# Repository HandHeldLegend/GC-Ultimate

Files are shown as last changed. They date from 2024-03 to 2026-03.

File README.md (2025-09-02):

# GC-Ultimate
This is the official Github page for the GC Ultimate from Hand Held Legend.

## Software and PCB License
<br />This firmware and PCB model are licensed under a <a rel="license" href="http://creativecommons.org/licenses/by-nc-sa/3.0/">Creative Commons Attribution-NonCommercial-ShareAlike 3.0 Unported License</a>.

## 3D Models License

<br />The 3D shell, buttons, and other associated models are licensed under a <a rel="license" href="http://creativecommons.org/licenses/by/4.0/">Creative Commons Attribution 4.0 International License</a>.

## Attributions

Resources Cross-Referenced for component placement and other spacing detail:
- 3D Scans by Wesk
- GCC CAD Model by GearHawk
- PhobGCC PCB
- 3D models for the ergonomic trigger reference were provided with full permission from *YaBoiMikey*

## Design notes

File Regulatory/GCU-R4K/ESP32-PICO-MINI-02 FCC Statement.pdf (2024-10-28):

9 U.S. FCC Statement

# 9 U.S. FCC Statement

Integration instructions for host product manufacturers according to KDB 996369 D03 OEM Manual v01:

1. List of applicable FCC rules
FCC Part 15 Subpart C 15.247 & 15.209
2. Specific operational use conditions
The module is a module with WiFi and BR,EDR,BLE function.
- Operation Frequency: WiFi 2412 ~2462 MHz;BT: 2402 ~ 2480 MHz
- Number of Channel:WiFi:12 ;BT: 40
- Modulation:WiFi:DSSS/OFDM ;BT:GFSK//4-DQPSK/8DPSK
- Type: PCB Antenna
- Gain: 3.96 dBi Max.

The module can be used for IoT applications with a maximum 3.96 dBi antenna. The host manufacturer installing this module into their product must ensure that the final composit product complies with the FCC requirements by a technical assessment or evaluation to the FCC rules, including the transmitter operation. The host manufacturer has to be aware not to provide information to the end user regarding how to install or remove this RF module in the user’s manual of the end product which integrates this module. The end user manual shall include all required regulatory information/warning as show in this manual.

3. Limited module procedures
Not applicable. The module is a single module and complies with the requirement of FCC Part 15.212.
4. Trace antenna designs
Not applicable. The module has its own antenna, and does not need a host’s printed board microstrip trace antenna, etc.
5. RF exposure considerations
The module must be installed in the host equipment such that at least 20cm is maintained between the antenna and users’ body; and if RF exposure statement or module layout is changed, then the host product manufacturer required to take responsibility of the module through a change in FCC ID or new application. The FCC ID of the module cannot be used on the final product. In these circumstances, the host manufacturer will be responsible for re-evaluating the end product (including the transmitter) and obtaining a separate FCC authorization.
6. Antennas
Antenna Specification are as follows:
- Type: PCB Antenna
- Gain: 3.96 dBi
- Type: Ipex Antenna
- Gain: 2.33 dBi

This device is intended only for host manufacturers under the following conditions:

- The transmitter module may not be co-located with any other transmitter or antenna.
Espressif Systems | 29 Submit Documentation Feedback
ESP32-PICO-MINI-02 & PICO-MINI-02U Datasheet v1.0

- The module shall be only used with the external antenna(s) that has been originally tested and certified with this module.
- The antenna must be either permanently attached or employ a ‘unique’ antenna coupler.

As long as the conditions above are met, further transmitter test will not be required. However, the host manufacturer is still responsible for testing their end-product for any additional compliance requirements required with this module installed (for example, digital device emissions, PC peripheral requirements, etc.).

7. Label and compliance information
Host product manufacturers need to provide a physical or e-label stating “Contains FCC ID: 2AC7Z-ESPPICOMINI” with their finished product.
8. Information on test modes and additional testing requirements
- Operation Frequency:WiFi 2412 ~2462 MHz;BT: 2402 ~ 2480 MHz
- Number of Channel:WiFi:12 ;BT: 40
- Modulation: WiFi:DSSS/OFDM ;BT:GFSK//4-DQPSK/8DPSK

Host manufacturer must perform test of radiated & conducted emission and spurious emission, etc., according to the actual test modes for a stand-alone modular transmitter in a host, as well as for multiple simultaneously transmitting modules or other transmitters in a host product. Only when all the test results of test modes comply with FCC requirements, then the end product can be sold legally.

9. Additional testing, Part 15 Subpart B compliant
The modular transmitter is only FCC authorized for FCC Part 15 Subpart C 15.247 & 15.209 and that the host product manufacturer is responsible for compliance to any other FCC rules that apply to the host not covered by the modular transmitter grant of certification. If the grantee markets their product as being Part 15 Subpart B compliant (when it also contains unintentional-radiator digital circuity), then the grantee shall provide a notice stating that the final host product still requires Part 15 Subpart B compliance testing with the modular transmitter installed.

This equipment has been tested and found to comply with the limits for a Class B digital device, pursuant to Part15 of the FCC Rules. These limits are designed to provide reasonable protection against harmful interference in a residential installation. This equipment generates, uses and can radiate radio frequency energy and, if not installed and used in accordance with the instructions, may cause harmful interference to radio communications. However, there is no guarantee that interference will not occur in a particular installation. If this equipment does cause harmful interference to radio or television reception, which can be determined by turning the equipment off and on, the user is encouraged to try to correct the interference by one of the following measures:

- Reorient or relocate the receiving antenna.
- Increase the separation between the equipment and receiver.
- Connect the equipment into an outlet on a circuit different from that to which the receiver is connected.
- Consult the dealer or an experienced radio/TV technician for help.

This device complies with Part 15 of the FCC Rules. Operation is subject to the following two conditions:

- This device may not cause harmful interference.
- This device must accept any interference received, including interference that may cause undesired operation.

Caution:

Any changes or modifications not expressly approved by the party responsible for compliance could void the user’s

authority to operate the equipment.

This equipment complies with FCC RF radiation exposure limits set forth for an uncontrolled environment. This device and its antenna must not be co-located or operating in conjunction with any other antenna or transmitter. The antennas used for this transmitter must be installed to provide a separation distance of at least 20 cm from all persons and must not be co-located or operating in conjunction with any other antenna or transmitter.

OEM Integration Instructions

This device is intended only for OEM integrators under the following conditions:

- The transmitter module may not be co-located with any other transmitter or antenna.
- The module shall be only used with the external antenna(s) that has been originally tested and certified with this module.

As long as the conditions above are met, further transmitter test will not be required. However, the OEM integrator is still responsible for testing their end-product for any additional compliance requirements required with this module installed (for example, digital device emissions, PC peripheral requirements, etc.).

Validity of Using the Module Certification

In the event that these conditions cannot be met (for example certain laptop configurations or co-location with another transmitter), then the FCC authorization for this module in combination with the host equipment is no longer considered valid and the FCC ID of the module cannot be used on the final product. In these circumstances, the OEM integrator will be responsible for re-evaluating the end product (including the transmitter) and obtaining a separate FCC authorization.

End Product Labeling

The final end product must be labeled in a visible area with the following: “Contains Transmitter Module FCC ID: 2AC7Z-ESPPICOMINI”.

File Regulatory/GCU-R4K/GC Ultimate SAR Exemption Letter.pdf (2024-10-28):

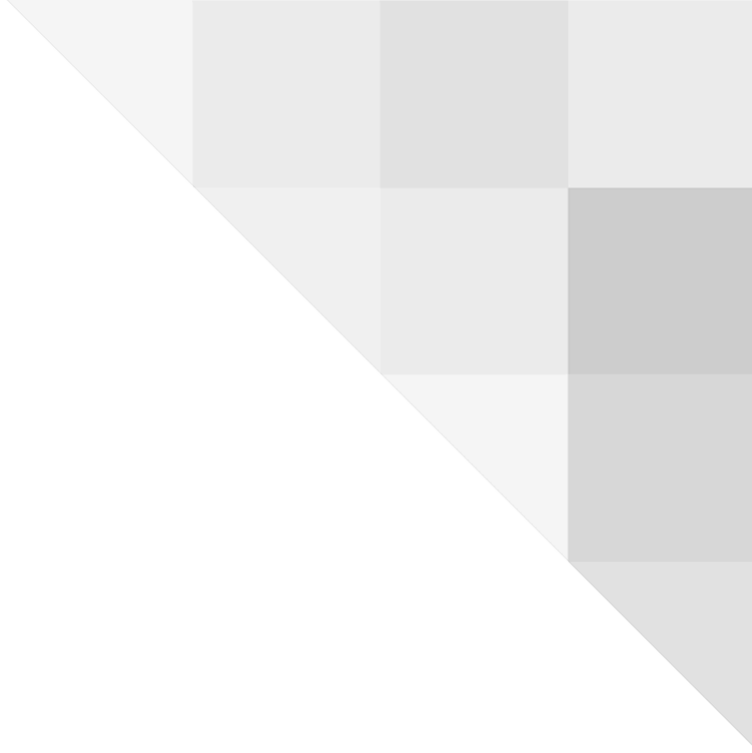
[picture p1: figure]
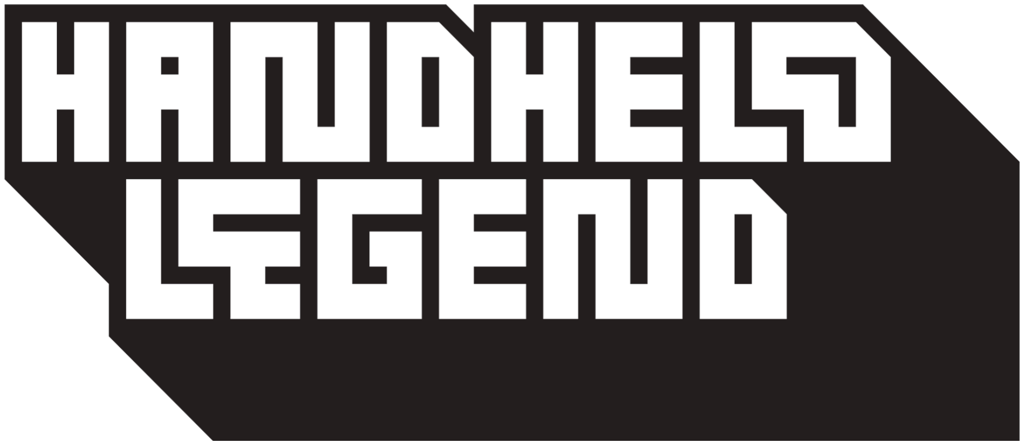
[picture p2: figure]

# SAR Testing Exemption Letter

Hand Held Legend, LLC

519 Davisville Rd, Unit 2, Willow Grove Pennsylvania 19090, United States

September 25th, 2024

To Whom It May Concern:

Re: SAR Testing Exemption for GC Ultimate Controller

This letter is to document the exemption from Specific Absorption Rate (SAR) testing for our product, GC Ultimate Controller, which utilizes Bluetooth Classic and Bluetooth Low Energy (BLE) technologies.

Product Details:

- Product Name: GC Ultimate Controller
- Model Number: GCU-R4K
- FCC ID: PENDING

We assert that this product is exempt from SAR testing requirements based on the following factors:

## Low Transmission Power:

The maximum transmission power of our device is set to 3 dBm (approximately 2 mW).

## Bluetooth Technology:

Our product exclusively uses Bluetooth Classic and Bluetooth Low Energy (BLE) technologies, which are designed for short-range, low-power communications.

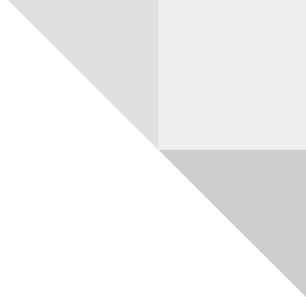
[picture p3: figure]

2

## Minimum Separation Distance:

The minimum distance from the user's hand to the transmitter is 1.5 cm, based on the controller's design when held by its two handles during normal use.

## RF Exposure Calculations:

We have performed calculations to demonstrate that our device complies with FCC RF exposure limits, taking into account the transmission power and minimum separation distance. The calculations are as follows:

a) Power Density Calculation:

Using the far-field equation for power density:

## S = EIRP / (4 * π * R²)

Where:

S = Power density (W/m²)

EIRP = Equivalent Isotropically Radiated Power (W)

R = Distance from the antenna (m)

EIRP = 2 mW = 0.002 W

R = 0.015 m (1.5 cm minimum distance)

S = 0.002 / (4 * π * 0.015²)

S = 0.707 W/m²

b) MPE Limit Comparison:

For uncontrolled environments, the FCC's MPE limit for the general public in the frequency range of 2-100 GHz is 1 mW/cm² (10 W/m²).

3

Our calculated power density (0.707 W/m²) is well below this limit, even at the minimum separation distance of 1.5 cm.

## Compliance with RF Exposure Limits:

Based on these calculations, we affirm that our product complies with FCC RF exposure limits for an uncontrolled environment, as specified in 47 CFR §2.1093, even at the minimum usage distance.

## Conservative Estimate:

These calculations represent a worst-case scenario, assuming continuous transmission at maximum power. In typical use, the actual average power may be lower due to the nature of Bluetooth communication protocols and usage patterns.

We maintain that our product meets all necessary safety standards and FCC requirements. Given the demonstrated compliance with RF exposure limits at the minimum usage distance, we believe our product qualifies for exemption from SAR testing.

If you require any further information or clarification, please do not hesitate to contact us.

Sincerely,

Mitchell Cairns, Lead Engineer, Hand Held Legend, LLC.

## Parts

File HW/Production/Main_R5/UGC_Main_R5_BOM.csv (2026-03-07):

# | Reference | Qty | MPN | Description | Value | Package | Link | LCSC | DNP
1 | R13,R33,R34,R35,R41 | 5 | RC0201FR-070RL | 50mW Thick Film Resistors 25V ±1% 0Ω | 0R | 0201 | https://www.lcsc.com/product-detail/Chip-Resistor-Surface-Mount_YAGEO-RC0201FR-070RL_C106227.html | C106227
2 | C28,C29 | 2 | CC0402FRNPO9BN150 | 50V 15pF NP0 ±1% | 15pF | 0402 | https://www.lcsc.com/product-detail/Multilayer-Ceramic-Capacitors-MLCC-SMD-SMT_YAGEO-CC0402FRNPO9BN150_C326803.html | C326803
3 | C1,C2 | 2 | CC0603JRX7R9BB473 | 50V 47nF X7R ±5% | 47nF | 0603 | https://www.lcsc.com/product-detail/Multilayer-Ceramic-Capacitors-MLCC-SMD-SMT_YAGEO-CC0603JRX7R9BB473_C519554.html | C519554
4 | C5,C6,C7,C9,C10,C11,C12,C13,C24,C25,C32 | 11 | CL03A104KQ3NNNC | 6.3V 100nF X5R ±10% | 100nF | 0201 | https://www.lcsc.com/product-detail/Multilayer-Ceramic-Capacitors-MLCC-SMD-SMT_Samsung-Electro-Mechanics-CL03A104KQ3NNNC_C160831.html | C160831
5 | C18 | 1 | CC0402KRX7R5BB104 | 6.3V 100nF X7R ±10% | 100nF | 0402 |  | C541406
6 | C15 | 1 | GRM033R60J474KE90D | CAP CER 470nF 6.3V X5R 0201 | 0.47uF | 0201 | https://www.lcsc.com/product-detail/C85926.html?s_z=n_C85926 | C85926
7 | C8,C14,C16,C19,C26,C27,C33,C34 | 8 | GRM033R60J105KEA2D | 6.3V 1uF X5R ±10% | 1uF | 0201 | https://www.lcsc.com/product-detail/Multilayer-Ceramic-Capacitors-MLCC-SMD-SMT_Murata-Electronics-GRM033R60J105KEA2D_C76929.html,https://www.lcsc.com/product-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 | C76929
8 | C4,C17,C23 | 3 | CL21A106KPFNNNE | 10V 10uF X5R ±10% | 10uF | 0805 | https://www.lcsc.com/product-detail/Multilayer-Ceramic-Capacitors-MLCC-SMD-SMT_Samsung-Electro-Mechanics-CL21A106KPFNNNE_C17024.html | C17024
9 | C3 | 1 | TAJA476K006RNJ | 47uF 6.3V 1.6Ω@100kHz ±10% | 47uF | CASE-A-3216-18(mm) | https://www.lcsc.com/product-detail/Tantalum-Capacitors_Kyocera-AVX-TAJA476K006RNJ_C7190.html | C7190
10 | R4,R6,R7,R36,R42 | 5 | RC0201FR-0727RL | 50mW Thick Film Resistors 25V ±1% ±200ppm/℃ 27Ω | 27R | 0201 | https://www.lcsc.com/product-detail/Chip-Resistor-Surface-Mount_YAGEO-RC0201FR-0727RL_C273268.html | C273268
11 | R3,R32,R40 | 3 | RC0201FR-07100RL | 50mW Thick Film Resistors 25V ±1% ±200ppm/℃ 100Ω | 100R | 0201 | https://www.lcsc.com/product-detail/Chip-Resistor-Surface-Mount_YAGEO-RC0201FR-07100RL_C77623.html | C77623
12 | R14,R30,R37 | 3 | RC0201FR-07100RL | 62.5mW Thick Film Resistors 50V ±100ppm/℃ ±1% 100Ω | 100R | 0201 |  | C77623
13 | R11 | 1 | RC0201FR-07330RL | 50mW Thick Film Resistors 25V ±1% ±200ppm/℃ 330Ω | 330R | 0201 | https://www.lcsc.com/product-detail/Chip-Resistor-Surface-Mount_YAGEO-RC0201FR-07330RL_C274872.html | C274872
14 | R17 | 1 | AC0201FR-07470RL | 50mW Thick Film Resistors ±1% ±200ppm/℃ 470Ω 0201 Chip Resistor - Surface Mount ROHS | 470R | 0201 |  | C226558
15 | R1,R2,R8,R9,R10,R12,R18,R19,R23,R24,R25,R26,R27,R28 | 14 | RC0201FR-071KL | 50mW Thick Film Resistors 25V ±1% ±200ppm/℃ 1kΩ | 1k | 0201 | https://www.lcsc.com/product-detail/Chip-Resistor-Surface-Mount_YAGEO-RC0201FR-071KL_C138165.html | C138165
16 | R21,R22 | 2 | RC0201FR-075K1L | 50mW Thick Film Resistors 25V ±1% ±200ppm/℃ 5.1kΩ | 5.1k | 0201 | https://www.lcsc.com/product-detail/Chip-Resistor-Surface-Mount_YAGEO-RC0201FR-075K1L_C274341.html | C274341
17 | R5,R15,R16,R20,R29,R31,R39 | 7 | RC0201FR-0710KL | 50mW Thick Film Resistors 25V ±1% ±200ppm/℃ 10kΩ | 10k | 0201 | https://www.lcsc.com/product-detail/Chip-Resistor-Surface-Mount_YAGEO-RC0201FR-0710KL_C106225.html | C106225
18 | R38 | 1 | RC0402FR-07100KL | 100kΩ 62.5mW 50V Thick Film Resistor ±100ppm/℃ ±1% 0402 Chip Resistor - Surface Mount RoHS | 100k | 0402 |  | C60491
19 | L5 | 1 | MIP25202R2MBE | 1.3A 2.2uH ±20% 80mΩ 1008 Inductors (SMD) ROHS | 1.3A 2.2uH ±20% 80mΩ | 1008 | https://www.lcsc.com/product-detail/Inductors-SMD_INPAQ-MIP25202R2MBE_C315721.html | C315721
20 | SW15 | 1 | 1TS026A-1000-0550 | 50mA 2.6mm 100MΩ 200,000 Times 12V 100gf 1.6mm 0.55mm Round Button Standing paste SPST SMD,1.6x2.6mm Tactile Switches ROHS | 1TS026A-1000-0550 | SMD,1.6x2.6mm | https://www.lcsc.com/product-detail/Tactile-Switches_HYP-Hongyuan-Precision-1TS026A-1000-0550-CT_C913778.html | C913778
21 | J2 | 1 | 5034800640 | Flip type -40℃~+85℃ 6P Dual-sided contacts / top and bottom connection Horizontal attachment 0.5mm SMD,P=0.5mm,Surface Mount，Right Angle FFC, FPC (Flat Flexible) Connector Assemblies ROHS | 503480-0640 | SMD,P=0.5mm,Surface Mount，Right Angle | https://www.lcsc.com/product-detail/FFC-FPC-Flat-Flexible-Connector-Assemblies_MOLEX-5034800640_C3168077.html | C3168077
22 | Y1 | 1 | ABM8-272-T3 | 12MHz SMD3225-4P Crystals ROHS | ABM8-272-T3 | SMD3225-4P | https://www.lcsc.com/product-detail/Crystals_Abracon-LLC-ABM8-272-T3_C20625731.html | C20625731
23 | D4,D5,D8,D11,D12,D13 | 6 | BAS16VY,115 | 3 Independent 200mA 1.25V@150mA 100V SOT-363 Diodes - General Purpose ROHS | BAS16VY,115 | SOT-363 | https://www.lcsc.com/product-detail/Diodes-General-Purpose_Nexperia-BAS16VY-115_C135826.html | C135826
24 | B1 | 1 | HDGC2001WV-2P | 1x2P 1 2P PH 2mm 2 2A Direct Insert Plugin,P=2mm Wire To Board Connector ROHS | Battery | Plugin,P=2mm | https://www.lcsc.com/product-detail/Wire-To-Board-Connector_HDGC-HDGC2001WV-2P_C5175230.html | C5175230
25 | L7 | 1 | BLM18AG601SN1D | Murata Electronics Ferrite Bead | BLM18AG601SN1D | 0603 |  | C19330
26 | U11 | 1 | BQ25180 | 5.5V Lithium-ion/Polymer 1 1A DSBGA-8(1.1x1.6) Battery Management ROHS | BQ25180 | DSBGA-8(1.1x1.6) | https://www.lcsc.com/product-detail/Battery-Management_Texas-Instruments-BQ25180YBGR_C3682423.html | C3682423
27 | IC1 | 1 | BQ27621YZFR-G1A | System-Side Fuel Gauge with Dynamic Voltage Correlation, Battery Gas Gauge | BQ27621YZFR-G1A | DSBGA-9 | https://www.lcsc.com/product-detail/C544417.html?s_z=n_BQ27621YZFR-G1A | C544417
28 | Q3,Q4 | 2 | BSS138DW-7-F | 50V 200mA 200mW 3.5Ω@10V,220mA 1.5V@250uA 2 N-Channel SC-70-6(SOT-363) MOSFETs ROHS | BSS138DW | SC-70-6(SOT-363) | https://www.lcsc.com/product-detail/MOSFETs_Diodes-Incorporated-BSS138DW-7-F_C154900.html | C154900
29 | J4,J5 | 2 | 5051100492 | -40℃~+105℃ Hinged Lid 4P 0.5mm 500mA 50V Bottom Contact Surface Mount, Right Angle SMD,P=0.5mm,Surface Mount,Right Angle FFC, FPC (Flat Flexible) Connector Assemblies RoHS | Conn_01x04_Socket | SMD,P=0.5mm,Surface Mount,Right Angle | https://www.lcsc.com/product-detail/C588007.html?s_z=n_5051100492 | C588007
30 | D1,D9,D10 | 3 | CUS08F30,H3F | SOD-323 Schottky Diodes ROHS | CUS08F30,H3F | SOD-323 | https://www.lcsc.com/product-detail/Schottky-Diodes_TOSHIBA-CUS08F30-H3F_C150183.html?s_z=n_C150183 | C150183
31 | U9 | 1 | GD25Q80EEIGR | 8Mbit 133MHz USON-8-EP(2x3) NOR FLASH ROHS | GD25Q80EEIGR | USON-8-EP(2x3) | https://www.lcsc.com/product-detail/NOR-FLASH_GigaDevice-Semicon-Beijing-GD25Q80EEIGR_C2874937.html | C2874937
32 | SW6 | 1 | GL1807SYAE-002 | TMR Analog Stick with button | GL18_SW
33 | D3,D6,D7,D14,D15,D16 | 6 | B5819WT | 40V Independent Type 1A 550mV SOD-523 Schottky Diodes ROHS | M7C | SOD-523 | https://www.lcsc.com/product-detail/Schottky-Diodes_LGE-B5819WT_C5364321.html | C5364321
34 | Q5,Q6 | 2 | MMBT2222A | 600mA Ic, 40V Vce, NPN Transistor, SOT-23 | MMBT2222A | SOT-23 | https://www.lcsc.com/product-detail/Bipolar-BJT_JSMSEMI-MMBT2222A_C916372.html | C916372
35 | J3 | 1 | 5051100792 | -40℃~+105℃ Hinged Lid 7P Bottom Contact Surface Mount, Right Angle 0.5mm SMD,P=0.5mm,Surface Mount,Right Angle FFC, FPC (Flat Flexible) Connector Assemblies ROHS | Molex 5051100792 | SMD,P=0.5mm,Surface Mount,Right Angle | https://lcsc.com/product-detail/FFC-FPC-Flat-Flexible-Connector-Assemblies_MOLEX-5051100792_C6689159.html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 | C6689159
36 | U8 | 1 | RP2040 | 264KB 30 133MHz LQFN-56(7x7) Microcontrollers | RP2040 | LQFN-56(7x7) | https://www.lcsc.com/product-detail/Microcontrollers-MCU-MPU-SOC_Raspberry-Pi-RP2040_C2040.html | C2040
37 | P1 | 1 | RPI-RM2 | Raspberry Pi RM2 Wireless Module | RPI-RM2
38 | L1,L2,L3,L4,L6,L8,L9,L10,L11,L12,L13,L14,L15,L16,L17,L18,L19 | 17 | SK6805-EC-10 | 0606 RGB LEDs(Built-in IC) ROHS | SK6805-EC-10 | 0606
39 | J1,J10 | 2 | SM02B-SURS-TF(LF)(SN) | Connector Header Surface Mount, Right Angle 2 position 0.031 (0.80mm) | SM02B-SURS-TF_LF__SN_ | SMD,P=0.8mm,Surface Mount，Right Angle | https://www.lcsc.com/product-detail/Wire-To-Board-Connector_JST-SM02B-SURS-TF-LF-SN_C566239.html | C566239
40 | U5,U10 | 2 | LSM6DSRTR | Accelerometer gyroscope LGA-14(2.5x3) Accelerometers ROHS | ST_LSM6 | LGA-14(2.5x3) | https://www.lcsc.com/product-detail/Accelerometers_STMicroelectronics-LSM6DSRTR_C784817.html | C784817
41 | SW7,SW8 | 2 | TC-00100V H5.0 100gf | Custom right angle silicone tactile switch 5mm button height | SW_Push | - | - | -
42 | S7 | 1 | TMUX1204DQAR | Multiplexer Switch ICs 5-V 4:1 general-purpose analog multiplexer 10-USON -40 to 125 | TMUX1204DQAR | USON-10(1x2.5) |  | C1849379
43 | U4 | 1 | TPS63001DRCR | High efficiency Buck-Boost Converter with 1.8A Current Switches in 3x3 QFN | TPS630001RCR | VSON-10 Texas Instruments | https://www.lcsc.com/product-detail/DC-DC-Converters_Texas-Instruments-TPS63001DRCR_C28060.html | C28060
44 | SW5,SW9,SW14,SW17,SW18,SW19 | 6 | TS-1187A-C-E-B | Single Pole Single Throw (SPST) switch | TS-1187A-C-A-B | SMD | https://www.lcsc.com/product-detail/Tactile-Switches_XKB-Connection-TS-1187A-C-A-B_C480267.html | C480267
45 | J11 | 1 | USB4056-03-A2 | USB Connectors USB C 3.2 Rec, Horz, Hybrid PCB Top Mount, T+R | USB4056-03-A2 |  | https://gct.co/files/specs/usb4056-spec.pdf
46 | U1,U2,U3 | 3 | USBLC6-2P6 | Very low capacitance ESD protection diode, 2 data-line, SOT-666 | USBLC6-2P6 | SOT-666-6 |  | C2827693

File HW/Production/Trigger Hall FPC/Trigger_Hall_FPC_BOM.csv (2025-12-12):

Reference | Qty | Value | Datasheet | Footprint | Manufacturer | MPN | LCSC | DNP
C1,C2 | 2 | 100n | ~ | Capacitor_SMD:C_0201_0603Metric | muRata | GRM033R61A104KE15D | C76934
U1,U2 | 2 | HAL4395 | https://www.lcsc.com/datasheet/C49165022.pdf | hhl:SOT-23-5L | Hallwee | HAL4395SO5 | C49165022

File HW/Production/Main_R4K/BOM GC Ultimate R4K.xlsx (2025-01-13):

NO | Designator | Quantity | Part Number（MPN) | Description | Value | Package | LCSC | Comment or Link | DNP
1 | B1,J6,J7 | 3 | HDGC2001WV-2P | 1x2P 1 2P PH 2mm 2 2A Direct Insert Plugin,P=2mm Wire To Board Connector ROHS | -- mixed values -- | Plugin,P=2mm | https://www.lcsc.com/product-detail/Wire-To-Board-Connector_HDGC-HDGC2001WV-2P_C5175230.html | C5175230
2 | C3 | 1 | TAJA476K006RNJ | 47uF 6.3V 1.6Ω@100kHz ±10% | 47uF | CASE-A-3216-18(mm) | https://www.lcsc.com/product-detail/Tantalum-Capacitors_Kyocera-AVX-TAJA476K006RNJ_C7190.html | C7190
3 | C1,C2 | 2 | CC0603JRX7R9BB473 | 50V 47nF X7R ±5% | 47nF | 603 | https://www.lcsc.com/product-detail/Multilayer-Ceramic-Capacitors-MLCC-SMD-SMT_YAGEO-CC0603JRX7R9BB473_C519554.html | C519554
4 | C28,C29 | 2 | CC0402FRNPO9BN150 | 50V 15pF NP0 ±1% | 15pF | 402 | https://www.lcsc.com/product-detail/Multilayer-Ceramic-Capacitors-MLCC-SMD-SMT_YAGEO-CC0402FRNPO9BN150_C326803.html | C326803
5 | C4,C17,C19,C23 | 4 | CL21A106KPFNNNE | 10V 10uF X5R ±10% | 10uF | 805 | https://www.lcsc.com/product-detail/Multilayer-Ceramic-Capacitors-MLCC-SMD-SMT_Samsung-Electro-Mechanics-CL21A106KPFNNNE_C17024.html | C17024
6 | C5,C6,C7,C9,C10,C11,C12,C13,C15,C18,C20,C22,C24,C25,C32 | 15 | CL03A104KQ3NNNC | 6.3V 100nF X5R ±10% | 100nF | 201 | https://www.lcsc.com/product-detail/Multilayer-Ceramic-Capacitors-MLCC-SMD-SMT_Samsung-Electro-Mechanics-CL03A104KQ3NNNC_C160831.html | C160831
7 | C8,C14,C16,C21,C26,C27,C33,C34 | 8 | GRM033R60J105KEA2D | 6.3V 1uF X5R ±10% | 1uF | 201 | https://www.lcsc.com/product-detail/Multilayer-Ceramic-Capacitors-MLCC-SMD-SMT_Murata-Electronics-GRM033R60J105KEA2D_C76929.html | C76929
8 | D1,D2,D9,D10 | 4 | TOSHIBA CUS08F30,H3F | SOD-323 Schottky Diodes ROHS | TOSHIBA CUS08F30,H3F | SOD-323 | https://www.lcsc.com/product-detail/Schottky-Diodes_TOSHIBA-CUS08F30-H3F_C150183.html | C150183
9 | D3,D6,D7,D14,D15,D16 | 6 | B5819WT | 40V Independent Type 1A 550mV SOD-523 Schottky Diodes ROHS | M7C | SOD-523 | https://www.lcsc.com/product-detail/Schottky-Diodes_LGE-B5819WT_C5364321.html | C5364321
10 | D4,D5,D8,D11,D12,D13 | 6 | BAS16VY,115 | 3 Independent 200mA 1.25V@150mA 100V SOT-363 Diodes - General Purpose ROHS | BAS16VY,115 | SOT-363 | https://www.lcsc.com/product-detail/Diodes-General-Purpose_Nexperia-BAS16VY-115_C135826.html | C135826
11 | J5 | 1 | UJ31-CH-G1-SMT-TR | Type C, USB 3.2 Gen 2, 10 Gbps, 20 Vac, 5 A, Right Angle, Surface Mount, Black Insulator, USB Receptacle | UJ31-CH-G1-SMT-TR | - | https://www.lcsc.com/product-detail/USB-Connectors_CUI-UJ31-CH-G1-SMT-TR_C22359729.html | C22359729
12 | J1,J10 | 2 | SM02B-SURS-TF(LF)(SN) | Connector Header Surface Mount, Right Angle 2 position 0.031 (0.80mm) | SM02B-SURS-TF_LF__SN_ | SMD,P=0.8mm,Surface Mount，Right Angle | https://www.lcsc.com/product-detail/Wire-To-Board-Connector_JST-SM02B-SURS-TF-LF-SN_C566239.html | C566239
13 | J2,J13 | 2 | 5034800640 | Flip type -40℃~+85℃ 6P Dual-sided contacts / top and bottom connection Horizontal attachment 0.5mm SMD,P=0.5mm,Surface Mount，Right Angle FFC, FPC (Flat Flexible) Connector Assemblies ROHS | 503480-0640 | SMD,P=0.5mm,Surface Mount，Right Angle | https://www.lcsc.com/product-detail/FFC-FPC-Flat-Flexible-Connector-Assemblies_MOLEX-5034800640_C3168077.html | C3168077
14 | L5 | 1 | MIP25202R2MBE | 1.3A 2.2uH ±20% 80mΩ 1008 Inductors (SMD) ROHS | 1.3A 2.2uH ±20% 80mΩ | 1008 | https://www.lcsc.com/product-detail/Inductors-SMD_INPAQ-MIP25202R2MBE_C315721.html | C315721
15 | L1,L2,L3,L4,L6,L10,L11,L12,L13 | 9 | SK6805-EC-15 | 0606 RGB LEDs(Built-in IC) ROHS | SK6805-EC-15 | 606 | https://www.lcsc.com/product-detail/RGB-LEDs-Built-in-IC_OPSCO-Optoelectronics-SK6805-EC15_C2890035.html | C2890035
16 | Q1,Q2 | 2 | MMBT3904 | 40V 200mW 100@100mA,1V 200mA NPN SOT-23 Bipolar (BJT) ROHS | MMBT3904 | SOT-23 | https://www.lcsc.com/product-detail/Bipolar-BJT_YONGYUTAI-MMBT3904_C2891808.html | C2891808
17 | Q3,Q4 | 2 | BSS138DW-7-F | 50V 200mA 200mW 3.5Ω@10V,220mA 1.5V@250uA 2 N-Channel SC-70-6(SOT-363) MOSFETs ROHS | BSS138DW | SC-70-6(SOT-363) | https://www.lcsc.com/product-detail/MOSFETs_Diodes-Incorporated-BSS138DW-7-F_C154900.html | C154900
18 | Q5,Q6 | 2 | MMBT2222A | 600mA Ic, 40V Vce, NPN Transistor, SOT-23 | MMBT2222A | SOT-23 | https://www.lcsc.com/product-detail/Bipolar-BJT_JSMSEMI-MMBT2222A_C916372.html | C916372
19 | R11 | 1 | RC0201FR-07330RL | 50mW Thick Film Resistors 25V ±1% ±200ppm/℃ 330Ω | 330R | 201 | https://www.lcsc.com/product-detail/Chip-Resistor-Surface-Mount_YAGEO-RC0201FR-07330RL_C274872.html | C274872
20 | R1,R2,R8,R9,R10,R12,R23,R24,R25,R26,R27,R28 | 12 | RC0201FR-071KL | 50mW Thick Film Resistors 25V ±1% ±200ppm/℃ 1kΩ | 1k | 201 | https://www.lcsc.com/product-detail/Chip-Resistor-Surface-Mount_YAGEO-RC0201FR-071KL_C138165.html | C138165
21 | R18,R19,R33,R34,R35,R41 | 6 | RC0201FR-070RL | 50mW Thick Film Resistors 25V ±1% 0Ω | 0R | 201 | https://www.lcsc.com/product-detail/Chip-Resistor-Surface-Mount_YAGEO-RC0201FR-070RL_C106227.html | C106227
22 | R21,R22 | 2 | RC0201FR-075K1L | 50mW Thick Film Resistors 25V ±1% ±200ppm/℃ 5.1kΩ | 5.1k | 201 | https://www.lcsc.com/product-detail/Chip-Resistor-Surface-Mount_YAGEO-RC0201FR-075K1L_C274341.html | C274341
23 | R3,R32,R40 | 3 | RC0201FR-07100RL | 50mW Thick Film Resistors 25V ±1% ±200ppm/℃ 100Ω | 100R | 201 | https://www.lcsc.com/product-detail/Chip-Resistor-Surface-Mount_YAGEO-RC0201FR-07100RL_C77623.html | C77623
24 | R4,R13,R14,R36,R37,R38 | 6 | AF0201FR-0775KL | 0mW Thick Film Resistors 25V ±1% ±200ppm/℃ 75kΩ | 75k | 201 | https://www.lcsc.com/product-detail/Chip-Resistor-Surface-Mount_YAGEO-AF0201FR-0775KL_C2107901.html | C2107901
25 | R5,R15,R16,R17,R20,R29,R30,R31,R39 | 9 | RC0201FR-0710KL | 50mW Thick Film Resistors 25V ±1% ±200ppm/℃ 10kΩ | 10k | 201 | https://www.lcsc.com/product-detail/Chip-Resistor-Surface-Mount_YAGEO-RC0201FR-0710KL_C106225.html | C106225
26 | R6,R7 | 2 | RC0201FR-0727RL | 50mW Thick Film Resistors 25V ±1% ±200ppm/℃ 27Ω | 27R | 201 | https://www.lcsc.com/product-detail/Chip-Resistor-Surface-Mount_YAGEO-RC0201FR-0727RL_C273268.html | C273268
27 | RV1,RV2 | 2 | RD7091008A | - | Slider_GCC-Gamecube_MB | - | - | - | DNP
28 | S1,S2,S3,S4,S5,S6 | 6 | 4015-0-43-80-30-27-10-0 | Generic connector, single row, 01x01, script generated | 4015-0-43-80-30-27-10-0 | - | https://www.lcsc.com/product-detail/Connector-Accessories_Mill-Max-Mfg-Corp-4015-0-43-80-30-27-10-0_C17526581.html | C17526581
29 | SW6 | 1 | GL1807SYAE-002 | TMR Analog Stick with button | GL18_SW
30 | SW15,SW16 | 2 | 1TS026A-1000-0550 | 50mA 2.6mm 100MΩ 200,000 Times 12V 100gf 1.6mm 0.55mm Round Button Standing paste SPST SMD,1.6x2.6mm Tactile Switches ROHS | 1TS026A-1000-0550 | SMD,1.6x2.6mm | https://www.lcsc.com/product-detail/Tactile-Switches_HYP-Hongyuan-Precision-1TS026A-1000-0550-CT_C913778.html | C913778
31 | SW5,SW9,SW14,SW17,SW18,SW19 | 6 | TS-1187A-C-E-B | Single Pole Single Throw (SPST) switch | TS-1187A-C-A-B | SMD | https://www.lcsc.com/product-detail/Tactile-Switches_XKB-Connection-TS-1187A-C-A-B_C480267.html | C480267
32 | SW7,SW8 | 2 | TC-00100V H5.0 100gf | Custom right angle silicone tactile switch 5mm button height | SW_Push | - | - | -
33 | U1 | 1 | ESP32-PICO-MINI-02 | 19.5dBm ESP32 chip 2.4GHz WiFi Modules ROHS | ESP32-PICO-MINI-02 | - | https://www.lcsc.com/product-detail/WiFi-Modules_Espressif-Systems-ESP32-PICO-MINI-02-N8R2_C2980306.html | C2980306
34 | U4 | 1 | TPS63001DRCR | High efficiency Buck-Boost Converter with 1.8A Current Switches in 3x3 QFN | TPS630001RCR | VSON-10 Texas Instruments | https://www.lcsc.com/product-detail/DC-DC-Converters_Texas-Instruments-TPS63001DRCR_C28060.html | C28060
35 | U8 | 1 | RP2040 | 264KB 30 133MHz LQFN-56(7x7) Microcontrollers | RP2040 | LQFN-56(7x7) | https://www.lcsc.com/product-detail/Microcontrollers-MCU-MPU-SOC_Raspberry-Pi-RP2040_C2040.html | C2040
36 | U9 | 1 | GD25Q80EEIGR | 8Mbit 133MHz USON-8-EP(2x3) NOR FLASH ROHS | GD25Q80EEIGR | USON-8-EP(2x3) | https://www.lcsc.com/product-detail/NOR-FLASH_GigaDevice-Semicon-Beijing-GD25Q80EEIGR_C2874937.html | C2874937
37 | U11 | 1 | BQ25180 | 5.5V Lithium-ion/Polymer 1 1A DSBGA-8(1.1x1.6) Battery Management ROHS | BQ25180 | DSBGA-8(1.1x1.6) | https://www.lcsc.com/product-detail/Battery-Management_Texas-Instruments-BQ25180YBGR_C3682423.html | C3682423
38 | U12 | 1 | CH340K | ESSOP-10-150mil-1mm USB Converters ROHS | CH340K | ESSOP-10-150mil-1mm | https://www.lcsc.com/product-detail/USB-Converters_WCH-Jiangsu-Qin-Heng-CH340K_C968586.html | C968586
39 | U13 | 1 | PI3USB4000AZUAEX | 8Ω 1 DPDT(DPDT) UQFN-10(1.5x2) Analog Switches, Multiplexers ROHS | PI3USB4000A | UQFN-10(1.5x2) | https://www.lcsc.com/product-detail/Analog-Switches-Multiplexers_Diodes-Incorporated-PI3USB4000AZUAEX_C294596.html | C294596
40 | U5,U10 | 2 | LSM6DSRTR | Accelerometer gyroscope LGA-14(2.5x3) Accelerometers ROHS | ST_LSM6 | LGA-14(2.5x3) | https://www.lcsc.com/product-detail/Accelerometers_STMicroelectronics-LSM6DSRTR_C784817.html | C784817
41 | U6,U7 | 2 | MCP3002-I/MS | 10 positions 2.7V~5.5V 200kHz SPI MSOP-8 Analog to Digital Converters (ADC) ROHS | MCP3002 | MSOP-8 | https://www.lcsc.com/product-detail/Analog-to-Digital-Converters-ADC_Microchip-Tech-MCP3002-I-MS_C635958.html | C635958
42 | Y1 | 1 | ABM8-272-T3 | 12MHz SMD3225-4P Crystals ROHS | ABM8-272-T3 | SMD3225-4P | https://www.lcsc.com/product-detail/Crystals_Abracon-LLC-ABM8-272-T3_C20625731.html | C20625731

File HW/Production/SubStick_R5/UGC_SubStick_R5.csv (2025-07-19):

# | Reference | Qty | MPN | Description | Value | Package | LCSC | Link | DNP
1 | SW1 | 1 | GL1807SYAE-002 | TMR Analog Stick with button | GL18_SW | - | - | -
2 | R1,R2 | 2 | RC0201FR-071KL | 50mW Thick Film Resistors 25V ±1% ±200ppm/℃ 1kΩ | 1k | 0201 | C138165 | https://www.lcsc.com/product-detail/Chip-Resistor-Surface-Mount_YAGEO-RC0201FR-071KL_C138165.html
3 | C1,C2 | 2 | CC0603JRX7R9BB473 | 50V 47nF X7R ±5% | 47nF | 0603 | C519554 | https://www.lcsc.com/product-detail/Multilayer-Ceramic-Capacitors-MLCC-SMD-SMT_YAGEO-CC0603JRX7R9BB473_C519554.html
4 | J1 | 1 | 5051100792 | -40℃~+105℃ Hinged Lid 7P Bottom Contact Surface Mount, Right Angle 0.5mm SMD,P=0.5mm,Surface Mount,Right Angle FFC, FPC (Flat Flexible) Connector Assemblies ROHS | Molex 5051100792 | SMD,P=0.5mm,Surface Mount,Right Angle | C6689159 | https://lcsc.com/product-detail/FFC-FPC-Flat-Flexible-Connector-Assemblies_MOLEX-5051100792_C6689159.html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
5 | RGB1,RGB2,RGB3,RGB4 | 4 | SK6805-EC-10 | RGB LED | SK6805-EC-10 | SK6805-EC-10 | C22394946 | https://cdn-shop.adafruit.com/product-files/5849/SK6805-EC10-000_REV.01_EN.pdf

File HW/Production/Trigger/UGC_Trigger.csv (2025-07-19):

# | Reference | Qty | MPN | Description | Value | Footprint | LCSC | Link | DNP
1 | RV1 | 1 | RD7091008A | Position sensor - PACK INDIVIDUALLY | Slider_GCC-Gamecube_SolderInsert | hhl:GCC_Slider_MillMaxSocketed | C127475 |  | DNP

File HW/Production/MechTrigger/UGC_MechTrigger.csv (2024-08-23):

Reference | Value | Footprint | Qty | DNP | MPN | Price
SW1 | SW_Push | hhl:PG1353 | 1 |  | CPG135301D03 | 0.45

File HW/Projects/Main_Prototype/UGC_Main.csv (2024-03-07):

# | Reference | Qty | Value | Footprint | DNP | MPN
1 | B1 | 1 | Battery | Connector_JST:JST_PH_B2B-PH-K_1x02_P2.00mm_Vertical
2 | C1, C2 | 2 | .047u | Capacitor_SMD:C_0603_1608Metric_Pad1.08x0.95mm_HandSolder
3 | C3 | 1 | 47uF 6.3v | Capacitor_Tantalum_SMD:CP_EIA-3216-18_Kemet-A
4 | C4, C23 | 2 | 10uF | Capacitor_SMD:C_0805_2012Metric
5 | C5, C7, C9, C10 | 4 | 100n | Capacitor_SMD:C_0402_1005Metric
6 | C6, C11, C15, C18, C20, C22, C24 | 7 | 100n | Capacitor_SMD:C_0201_0603Metric
7 | C8 | 1 | 1u | Capacitor_SMD:C_0402_1005Metric
8 | C12, C13 | 2 | 100nF | Capacitor_SMD:C_0603_1608Metric
9 | C14, C16, C21 | 3 | 1u | Capacitor_SMD:C_0201_0603Metric
10 | C17 | 1 | 10uF | Capacitor_SMD:C_0402_1005Metric
11 | C19 | 1 | 10uF/10V (20%) | Capacitor_SMD:C_0603_1608Metric
12 | D1, D2, D9, D10 | 4 | CUS08F30 | Diode_SMD:D_SOD-323_HandSoldering |  | CUS08F30
13 | D3 | 1 | M7C | Diode_SMD:D_SOD-123 |  | B5819W SL
14 | D4, D5, D6, D7, D8 | 5 | BAS16VY,115 | Package_TO_SOT_SMD:SOT-363_SC-70-6
15 | F1, F2 | 2 | Fuse | Fuse:Fuse_1206_3216Metric_Pad1.42x1.75mm_HandSolder
16 | J5 | 1 | UJ31-CH-G1-SMT-TR | hhl:CUI_UJ31-CH-G1-SMT-TR |  | UJ31-CH-G1-SMT-TR
17 | J13 | 1 | 503480-0640 | hhl:5034800640 |  | 503480-0640
18 | L1, L2, L3, L4 | 4 | SK6805-EC-15 | hhl:SK6805-EC-15 |  | SK6805-EC-15
19 | L5 | 1 | 1.3A 2.2uH ±20% 80mΩ | Inductor_SMD:L_1008_2520Metric |  | MIP25202R2MBE
20 | Q1, Q2 | 2 | MMBT3904 | Package_TO_SOT_SMD:SOT-23 |  | MMBT3904
21 | Q3, Q4 | 2 | BSS138DW | Package_TO_SOT_SMD:SOT-363_SC-70-6 |  | BSS138DW-7-F
22 | Q5, Q7 | 2 | Q_NMOS_GSD | Package_TO_SOT_SMD:SOT-23 |  | AO3400A
23 | Q6 | 1 | Q_PMOS_GDS | Package_TO_SOT_SMD:SOT-23 |  | AO3401A
24 | R1, R2, R8, R9, R10, R12, R23, R24, R25, R26, R27, R28 | 12 | 1k | Resistor_SMD:R_0201_0603Metric
25 | R3 | 1 | 100 | Resistor_SMD:R_0201_0603Metric
26 | R4, R13, R14, R36, R37, R38 | 6 | 75k | Resistor_SMD:R_0603_1608Metric
27 | R5, R15, R16, R17, R20, R29, R30, R31, R33, R34 | 10 | 10k | Resistor_SMD:R_0201_0603Metric
28 | R6, R7 | 2 | 27 | Resistor_SMD:R_0201_0603Metric
29 | R11 | 1 | 330 | Resistor_SMD:R_0402_1005Metric
30 | R18, R19 | 2 | 0 | Resistor_SMD:R_0201_0603Metric
31 | R21, R22 | 2 | 5.1kohm | Resistor_SMD:R_0603_1608Metric
32 | R32, R35 | 2 | 100R | Resistor_SMD:R_0201_0603Metric
33 | RV1, RV2 | 2 | Slider_GCC-Gamecube_MB | hhl:GCC_Slider |  | RD7091008A
34 | SW6 | 1 | GL18_SW | hhl:GL18 |  | GL18
35 | SW7, SW8 | 2 | SW_Push | hhl:Z_Switch_Edge_Omron |  | TC-00100V H5.0 100gf
36 | SW9, SW14 | 2 | TS09-63-25-R-260-SMT | hhl:TS09 |  | TS09-63-25-R-260-SMT
37 | SW15, SW16 | 2 | 1TS026A-1000-0550 | hhl:1TS026A-1000-0550 |  | 1TS026A-1000-0550
38 | U1 | 1 | ESP32-PICO-MINI-02 | hhl:MODULE_ESP32-PICO-MINI-02 |  | ESP32-PICO-MINI-02
39 | U2, U3 | 2 | GH39F (Hall SOT23) | hhl:GH39F |  | GH39F
40 | U4 | 1 | TPS630001RCR | hhl:VREG_V62_16624-01YE |  | TPS63001DRCR
41 | U5, U10 | 2 | ST_LSM6 | hhl:LGA14 |  | LSM6DSRTR
42 | U6, U7 | 2 | MCP3002 | Package_SO:MSOP-8_3x3mm_P0.65mm |  | MCP3002-I/MS
43 | U8 | 1 | RP2040 | Package_DFN_QFN:QFN-56-1EP_7x7mm_P0.4mm_EP3.2x3.2mm |  | RP2040
44 | U9 | 1 | GD25Q80EEIGR | hhl:USON-8-EP(2x3) |  | GD25Q80EEIGR
45 | U11 | 1 | BQ25180 | hhl:DSBGA |  | BQ25180
46 | U12 | 1 | CH340K | hhl:ESSOP-10 |  | CH340K
47 | U13 | 1 | PI3USB4000A | Package_DFN_QFN:Texas_UQFN-10_1.5x2mm_P0.5mm |  | PI3USB4000AZUAEX
48 | Y1 | 1 | Crystal_GND3 | Crystal:Resonator_SMD_Murata_CSTxExxV-3Pin_3.0x1.1mm |  | CSTNE12M0GH5L000R0

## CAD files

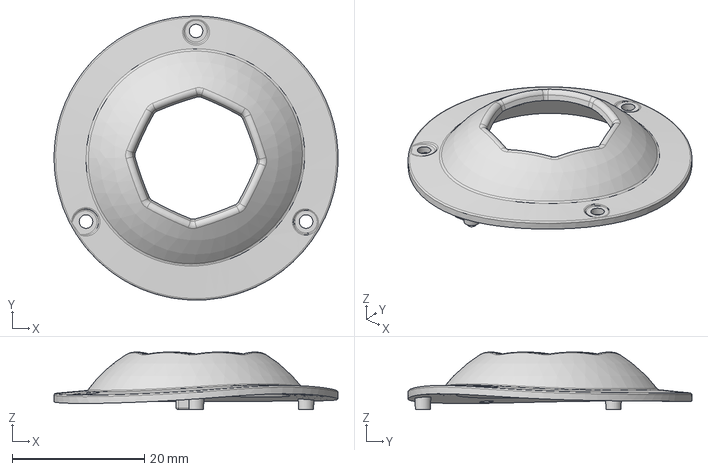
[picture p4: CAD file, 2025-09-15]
CAD/GatePlateOctagon.step
43.0 x 43.0 x 9.21 mm

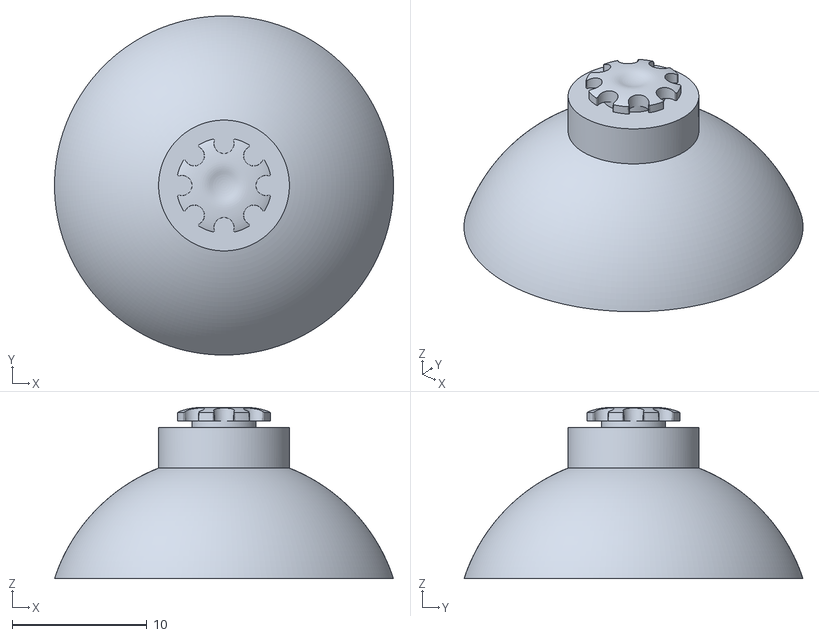
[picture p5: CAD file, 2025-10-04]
CAD/Printable/CStickBase.stl
25.1 x 25.1 x 12.7

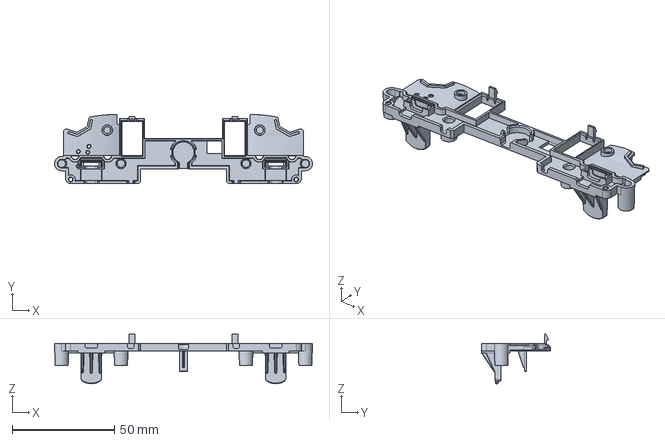
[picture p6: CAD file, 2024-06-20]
CAD/Prototype/Trigger Bracket.step
125.9 x 33.8 x 24.2 mm

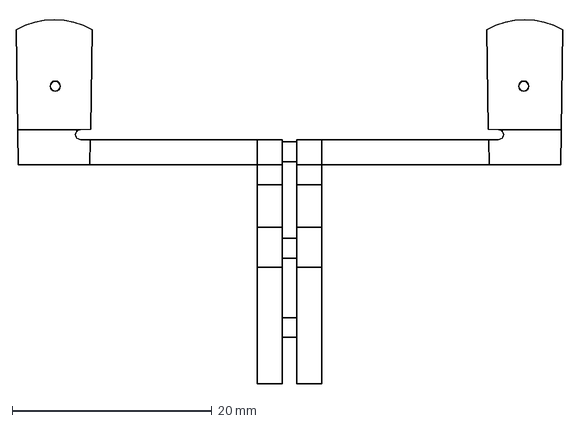
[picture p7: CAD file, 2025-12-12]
HW/Projects/Trigger Hall FPC/TriggerHallFPCDrawing.dxf
54.7 x 36.8 mm

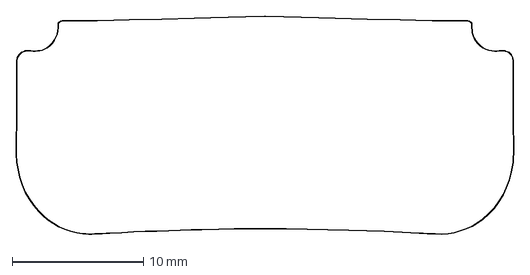
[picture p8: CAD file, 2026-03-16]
Regulatory/GCU_FCC_LABEL.dxf
37.9 x 16.7 mm

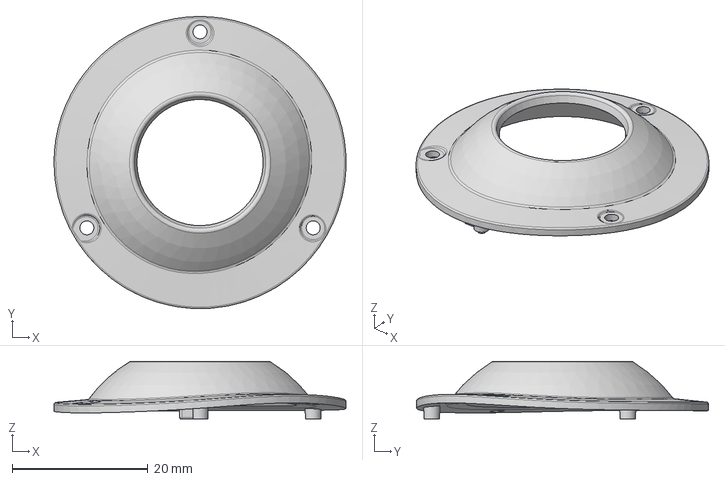
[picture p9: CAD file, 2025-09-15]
CAD/GatePlateRound.step
43.0 x 43.0 x 9.02 mm

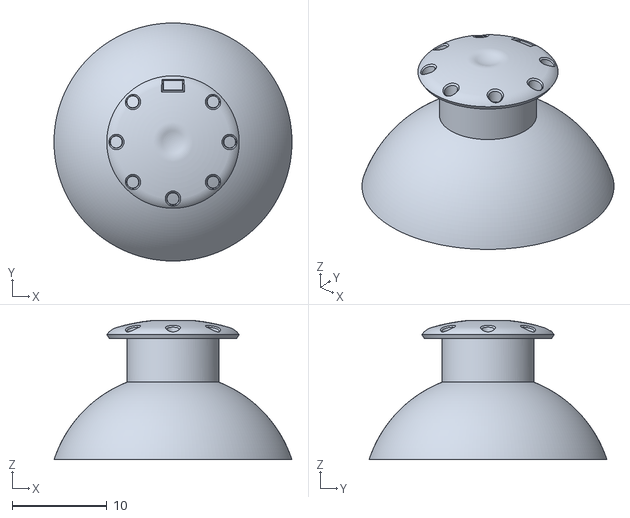
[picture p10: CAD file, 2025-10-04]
CAD/Printable/StickBase.stl
25.1 x 25.1 x 14.7

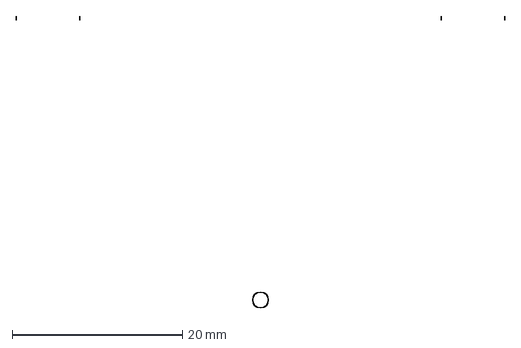
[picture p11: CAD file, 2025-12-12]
HW/Projects/Trigger Hall FPC/PLACEMENTGUIDE.dxf
57.4 x 34.3 mm

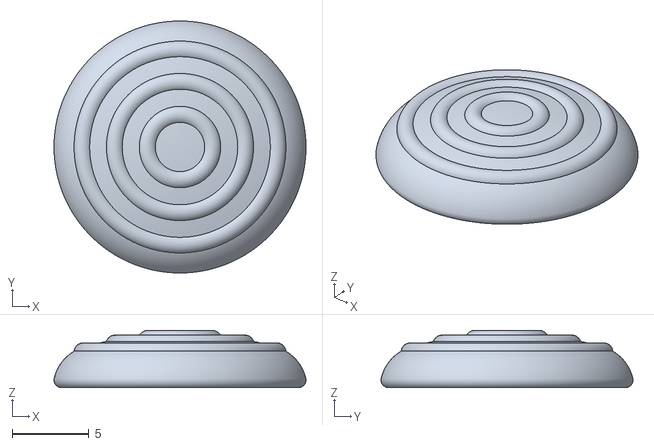
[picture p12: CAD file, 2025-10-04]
CAD/Printable/StickRubber.stl
16.4 x 16.4 x 3.73

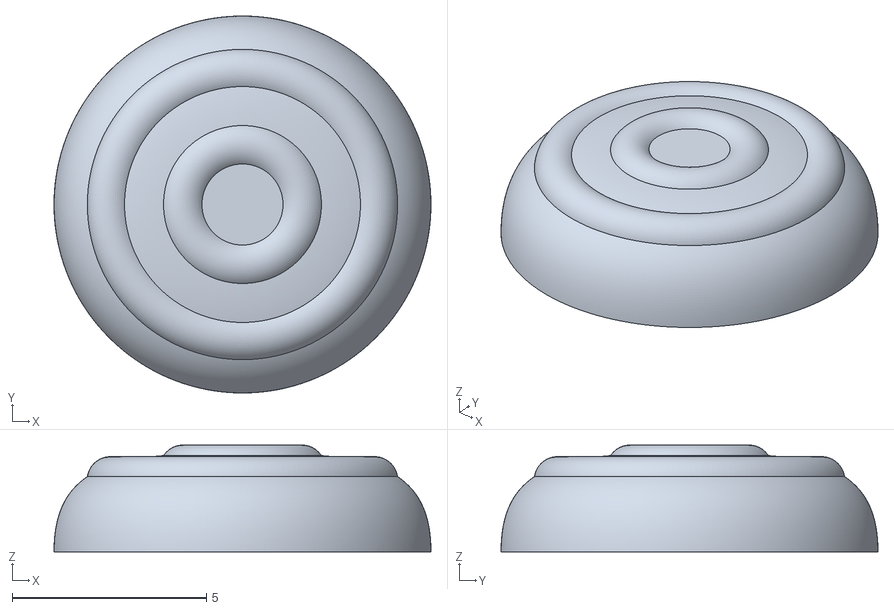
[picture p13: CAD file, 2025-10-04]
CAD/Printable/CStickRubber.stl
9.70 x 9.70 x 2.75

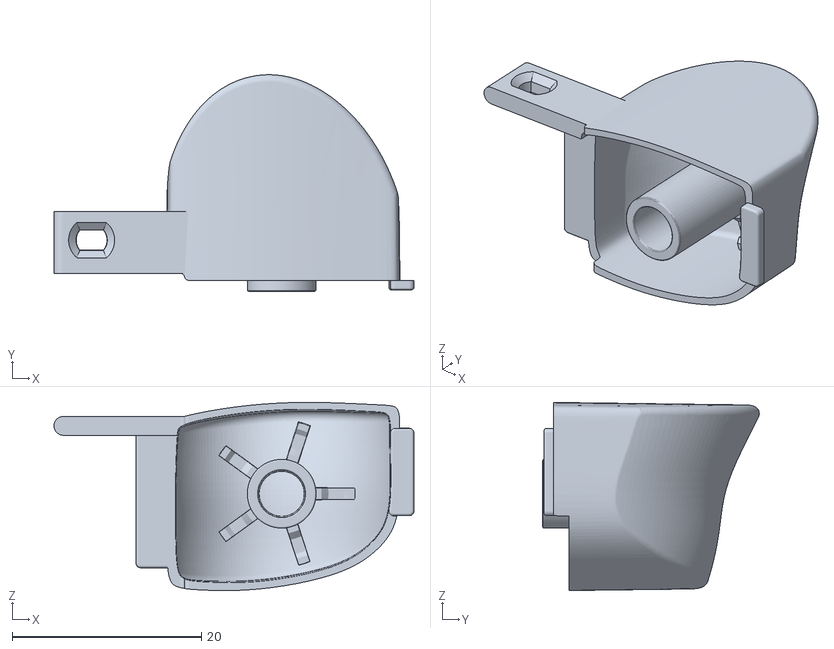
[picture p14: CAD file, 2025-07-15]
CAD/Printable/R Trigger.stl
38.0 x 22.9 x 19.9

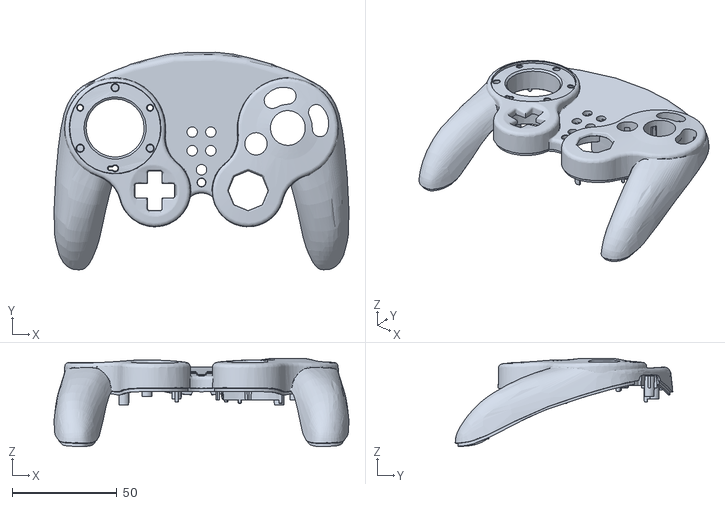
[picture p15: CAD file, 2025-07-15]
CAD/Printable/Top Shell.stl
140.6 x 103.7 x 42.0

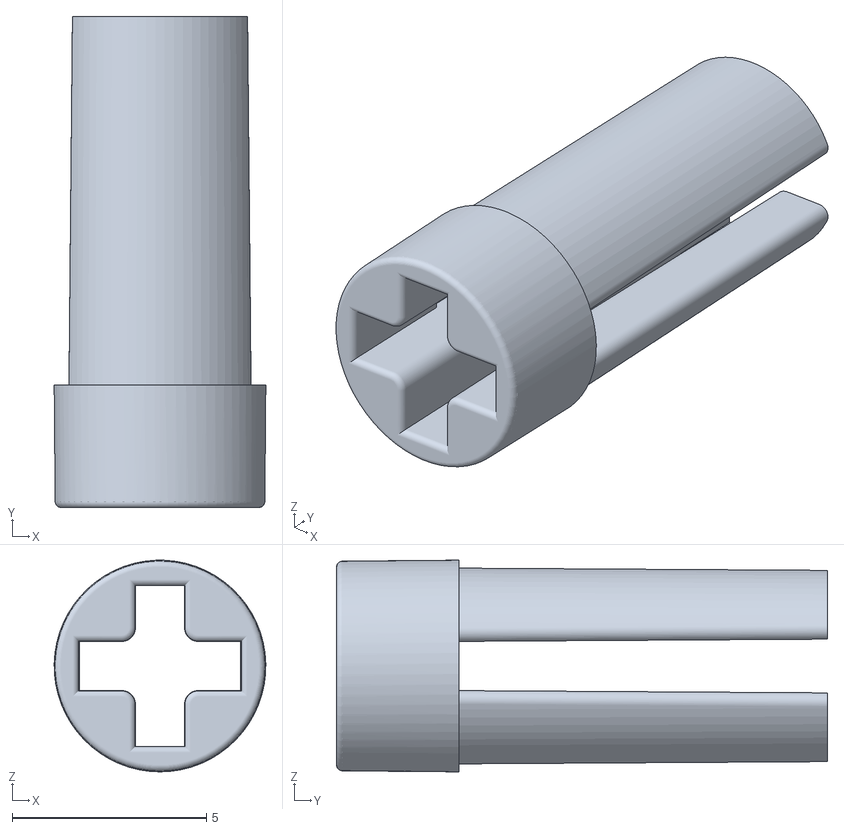
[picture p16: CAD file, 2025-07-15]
CAD/Printable/Kailh Stem.stl
5.45 x 12.6 x 5.45

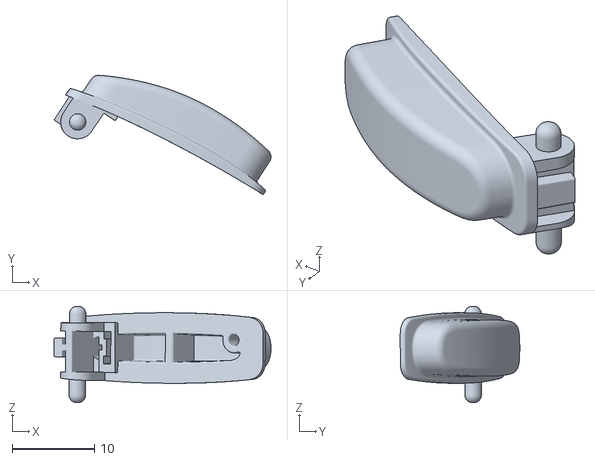
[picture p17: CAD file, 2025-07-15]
CAD/Printable/ZR Button.stl
26.4 x 14.6 x 11.7

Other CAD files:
CAD/Printable/Octagonal Gateplate.stl
CAD/Printable/Round Gateplate.stl
CAD/Printable/L Trigger.stl
CAD/Printable/Split Dpad.stl
CAD/Printable/Light Pipe.stl
CAD/Printable/Mechanical Trigger Bracket.stl
CAD/Printable/Membrane Trigger Holder.stl
CAD/Printable/ZL Button.stl

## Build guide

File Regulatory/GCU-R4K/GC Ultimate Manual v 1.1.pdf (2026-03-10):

# USER MANUAL

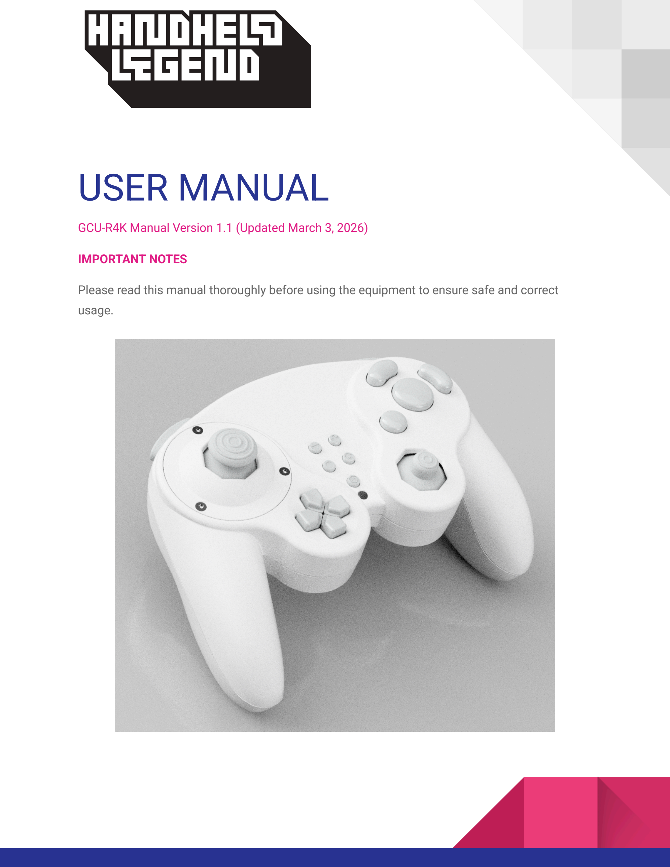
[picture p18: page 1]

GCU-R4K Manual Version 1.1 (Updated March 3, 2026)

IMPORTANT NOTES

Please read this manual thoroughly before using the equipment to ensure safe and correct usage.

# Operating Instructions

## Basic Operation

Hold the Power button to turn the device on or off. When the device is connected via USB-C connection, the device will automatically power on without wireless capability.

When the device is powered on while Holding Sync Buttons, the device will power on and allow sync mode (Bluetooth).

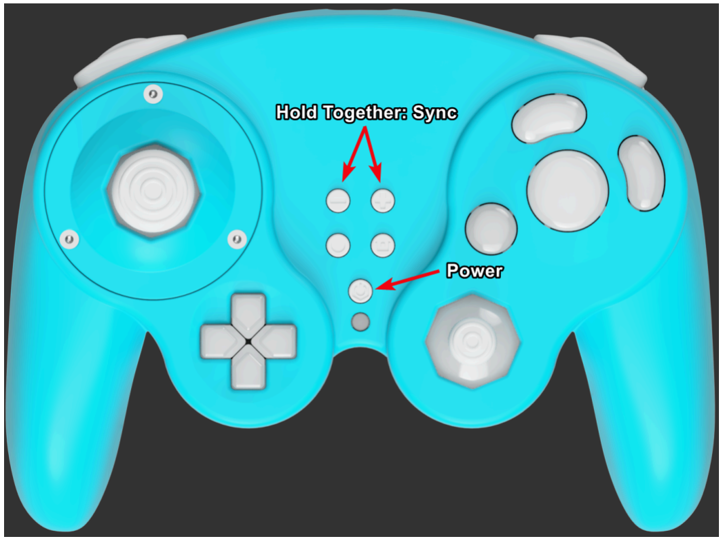
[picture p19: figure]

## Controller Diagram

See all of the various available buttons and input devices for use during gameplay.

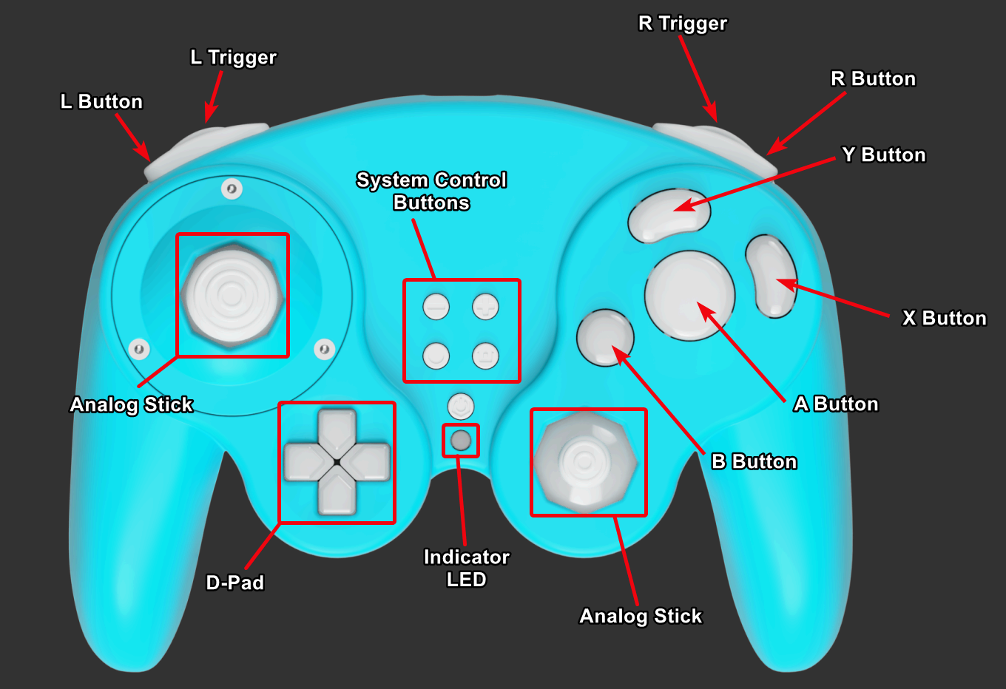
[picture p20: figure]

## Charging and Power

This device allows charging using USB-PD compliant chargers and cables. Ensure that the cable and/or charger that you are using are USB-IF or USB-PD compliant. See the diagram below for where to locate the USB-C connection.

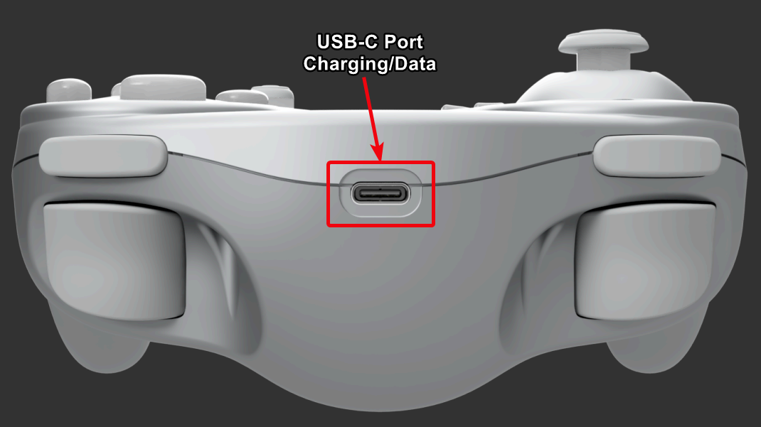
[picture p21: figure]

# FCC Information

## FCC ID Label Location

The FCC ID Label can be located on the rear side of the device.

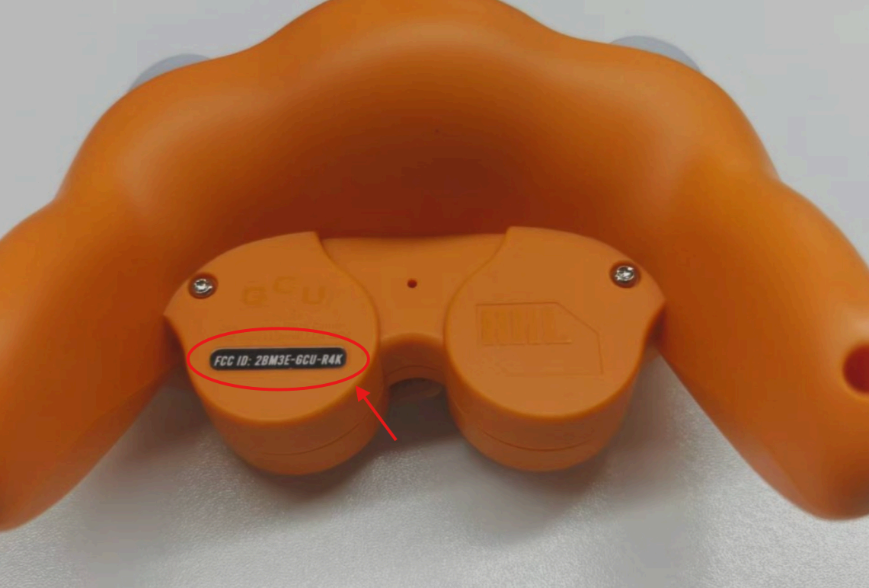
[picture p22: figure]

## FCC Compliance Statement and E-Labeling

This device complies with part 15 of the FCC Rules. Operation is subject to the following two conditions: (1) This device may not cause harmful interference, and (2) this device must accept any interference received, including interference that may cause undesired operation.

Note on Labeling: Due to the ergonomic design and complex surface texture of the gamepad, it is impracticable to place the full compliance statement on the device housing. Per FCC Rule 15.19(a)(5), the full statement is provided here in the user manual and via the electronic label.

How to Access E-Label: > Regulatory information, including the FCC ID and Part 15 statement, can be accessed at any time through the configuration software:

1. Connect the gamepad to the gamepad configuration app (Chrome/Opera Browser Required: https://handheldlegend.github.io/hoja2/
2. Navigate to the 'Wireless' tab.

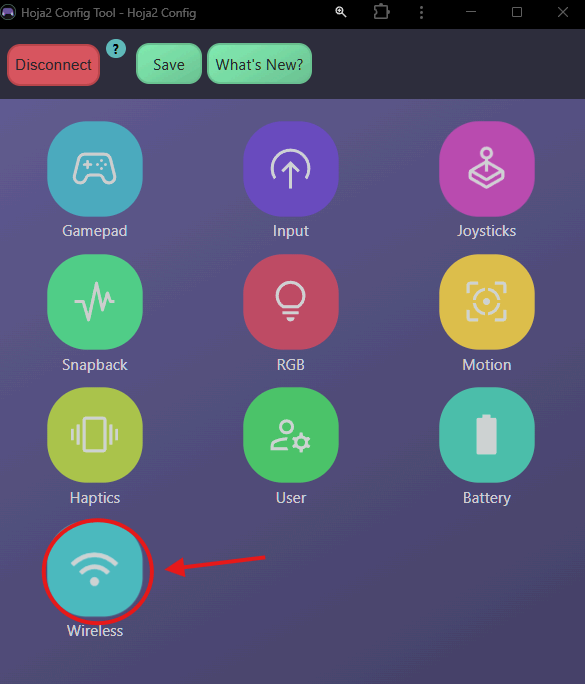
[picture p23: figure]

3. View the 'Regulatory Information' section.

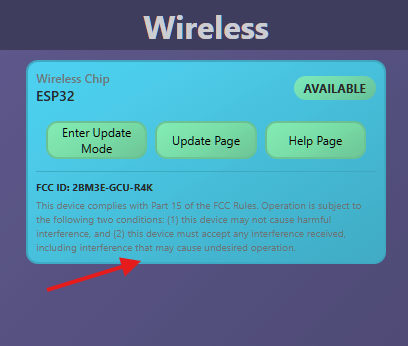
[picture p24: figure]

## FCC notice "Declaration of Conformity Information"

This equipment has been tested and found to comply with the limits for a Class B digital device, pursuant to part 15 of the FCC rules. These limits are designed to provide reasonable protection against harmful interference in a residential installation. This equipment generates, uses and can radiate radio frequency energy and, if not installed and used in accordance with the instructions, may cause harmful interference to radio communications. However, there is no guarantee that interference will not occur in a particular installation. If this equipment does cause harmful interference to radio or television reception, which can be determined by turning the equipment off and on, the user is encouraged to try to correct the interference by one or more of the following measures:

1. Reorient or relocate the receiving antenna.
2. Increase the separation between the equipment and receiver.
3. Connect the equipment into an outlet on a circuit different from that to which the receiver is connected.
4. Consult the dealer or an experienced radio/TV technician for help.

## FCC Conditions

This equipment has been tested and found to comply with Part 15 of the FCC Rules. Operation is subject to the following two conditions:

(1) This device may not cause harmful interference
(2) This device must accept any interference received, including interference that may cause undesired operation.

## FCC Notice "Equipment Authorization" Information

This device complies with part 15 of the FCC Rules. Operation is subject to the following two conditions:

(1) this device may not cause harmful interference, and
(2) this device must accept any interference received, including interference that may cause undesired operation.

## FCC Radiation Exposure Statement:

This equipment complies with FCC radiation exposure limits set forth for an uncontrolled environment.

NOTE : Any changes or modifications to this unit not expressly approved by the party responsible for compliance could void the user's authority to operate the equipment.

# Important Safety Information

Throughout these instructions, you will see this symbol followed by WARNING or CAUTION, or you may see the term NOTICE.

These terms have different levels of meaning as outlined below.

Please read and understand these terms and the information that appears after them before using your device.

WARNING Warns you about incorrect use of this system that could result in serious personal injury.

CAUTION Cautions you about incorrect use of this system that could result in personal injury or damage to the system, components, games, or accessories.

NOTICE Informs you about incorrect use of the system that could result in damage to the system, components, or accessories.

Some people (about 1 in 4,000) may have seizures or blackouts triggered by light flashes or patterns, and this may occur while they are watching TV or playing video games, even if they have never had a seizure before. This device features LED indicator lights which may be configured to flash at a high interval rate.

Anyone who has had a seizure, loss of awareness, or other symptom linked to an epileptic condition should consult a doctor before playing a video game. Playing video games can make your muscles, joints, skin, or eyes hurt. Follow these instructions to avoid problems such as tendinitis, carpal tunnel syndrome, skin irritation or eye strain:

Avoid excessive play. Parents should monitor their children for appropriate play. Take a 10 to 15 minute break every hour, even if you don't think you need it.

If your hands, wrists, arms, or eyes become tired or sore while playing, or if you feel symptoms such as tingling, numbness, burning, or stiffness, stop and rest for several hours before playing again. If you continue to have any of the above symptoms or other discomfort during or after play, stop playing and see a doctor.

Do not use an AC adapter if it has damaged, split, or broken cords or wires.

ELECTRIC SHOCK Make sure that the AC adapter cord is fully inserted into the wall outlet or extension cord. Always carefully disconnect all plugs by pulling on the plug and not on the cord.

DANGER - TO REDUCE THE RISK OF FIRE OR ELECTRIC SHOCK, CAREFULLY FOLLOW THESE INSTRUCTIONS For connection to a supply not in the U.S.A., use an attachment plug adapter of the proper configuration for the power outlet, if needed. The GC Ultimate controllers may contain a rechargeable lithium ion battery. Leakage of ingredients contained within the battery, or the combustion products of the ingredients, can cause personal injury as well as damage to other components. If battery leakage occurs, avoid contact with skin. If contact occurs, immediately wash thoroughly with soap and water. If liquid leaking from a battery comes into contact with your eyes, immediately flush thoroughly with water and see a doctor. To avoid battery leakage: Do not expose battery to excessive physical shock, vibration, or liquids. Do not disassemble, attempt to repair, or deform the battery. Do not dispose of battery in a fire. Do not touch the terminals of the battery or cause a short between the terminals with a metal object.

The GC Ultimate controller can emit radio waves that can affect the operation of nearby electronics, including cardiac pacemakers.

Do not operate the GC Ultimate controller within 9 inches of a pacemaker.

If you have a pacemaker or other implanted medical device, do not use the GC Ultimate controller without first consulting your doctor or the manufacturer of your medical device.

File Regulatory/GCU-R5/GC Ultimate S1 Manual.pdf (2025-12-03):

# USER MANUAL

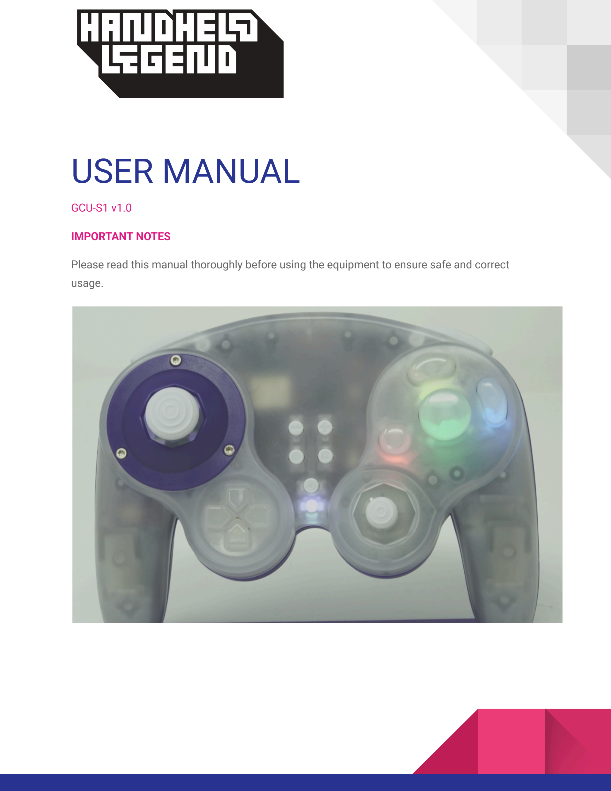
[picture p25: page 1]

GCU-S1 v1.0

IMPORTANT NOTES

Please read this manual thoroughly before using the equipment to ensure safe and correct usage.

# Operating Instructions

## Basic Operation

When the device is connected via USB-C connection, the device will automatically power on in a wired mode.Controller Diagram

See all of the various available buttons and input devices for use during gameplay.

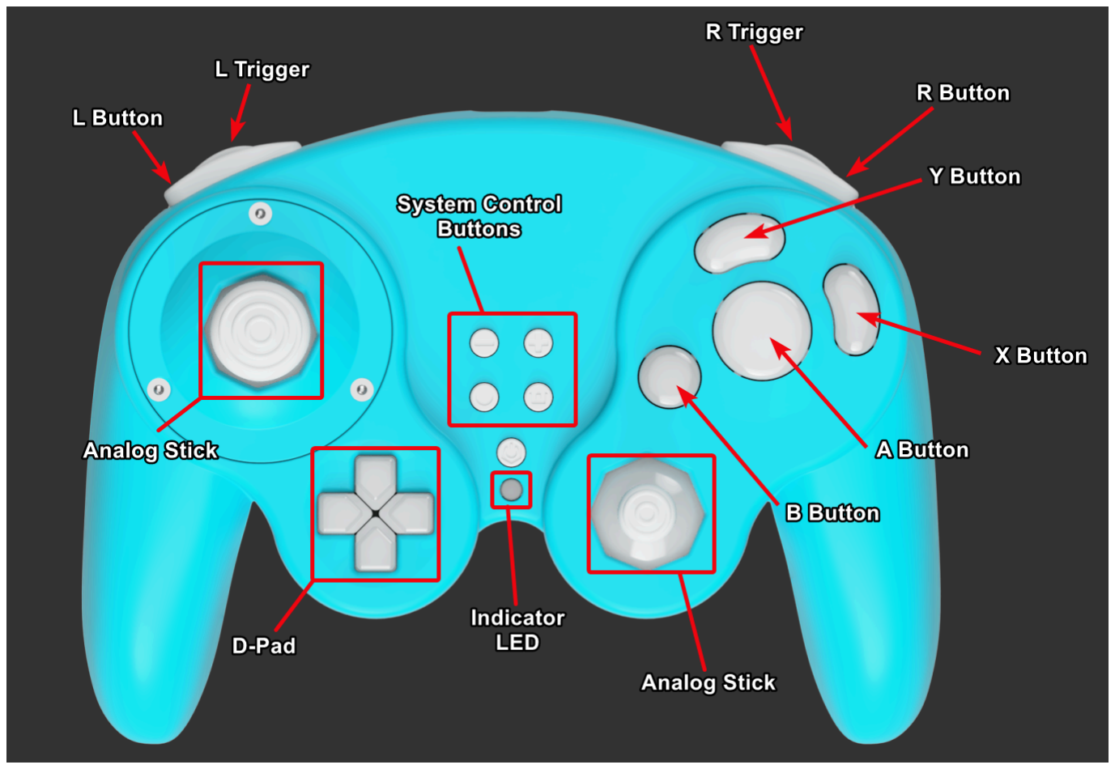
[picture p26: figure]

## Data and Power

This device allows power using USB-PD compliant cables. Ensure that the cable and/or game console that you are using are USB-IF or USB-PD compliant. See the diagram below for where to locate the USB-C connection.


# FCC Information

## FCC notice "Declaration of Conformity Information"

This equipment has been tested and found to comply with the limits for a Class B digital device, pursuant to part 15 of the FCC rules. These limits are designed to provide reasonable protection against harmful interference in a residential installation. This equipment generates, uses and can radiate radio frequency energy and, if not installed and used in accordance with the instructions, may cause harmful interference to radio communications. However, there is no guarantee that interference will not occur in a particular installation. If this equipment does cause harmful interference to radio or television reception, which can be determined by turning the equipment off and on, the user is encouraged to try to correct the interference by one or more of the following measures:

1. Reorient or relocate the receiving antenna.
2. Increase the separation between the equipment and receiver.
3. Connect the equipment into an outlet on a circuit different from that to which the receiver is connected.
4. Consult the dealer or an experienced radio/TV technician for help.

## FCC Conditions

This equipment has been tested and found to comply with Part 15 of the FCC Rules. Operation is subject to the following two conditions:

(1) This device may not cause harmful interference
(2) This device must accept any interference received, including interference that may cause undesired operation.

## FCC Notice "Equipment Authorization" Information

This device complies with part 15 of the FCC Rules. Operation is subject to the following two conditions:

(1) this device may not cause harmful interference, and
(2) this device must accept any interference received, including interference that may cause undesired operation.

## FCC Radiation Exposure Statement:

This equipment complies with FCC radiation exposure limits set forth for an uncontrolled environment.

NOTE : Any changes or modifications to this unit not expressly approved by the party responsible for compliance could void the user's authority to operate the equipment.

# Important Safety Information

Throughout these instructions, you will see this symbol followed by WARNING or CAUTION, or you may see the term NOTICE.

These terms have different levels of meaning as outlined below.

Please read and understand these terms and the information that appears after them before using your device.

WARNING Warns you about incorrect use of this system that could result in serious personal injury.

CAUTION Cautions you about incorrect use of this system that could result in personal injury or damage to the system, components, games, or accessories.

NOTICE Informs you about incorrect use of the system that could result in damage to the system, components, or accessories.

Some people (about 1 in 4,000) may have seizures or blackouts triggered by light flashes or patterns, and this may occur while they are watching TV or playing video games, even if they have never had a seizure before. This device features LED indicator lights which may be configured to flash at a high interval rate.

Anyone who has had a seizure, loss of awareness, or other symptom linked to an epileptic condition should consult a doctor before playing a video game. Playing video games can make your muscles, joints, skin, or eyes hurt. Follow these instructions to avoid problems such as tendinitis, carpal tunnel syndrome, skin irritation or eye strain:

Avoid excessive play. Parents should monitor their children for appropriate play. Take a 10 to 15 minute break every hour, even if you don't think you need it.

If your hands, wrists, arms, or eyes become tired or sore while playing, or if you feel symptoms such as tingling, numbness, burning, or stiffness, stop and rest for several hours before playing again. If you continue to have any of the above symptoms or other discomfort during or after play, stop playing and see a doctor.

Do not use an AC adapter if it has damaged, split, or broken cords or wires.

ELECTRIC SHOCK Make sure that the AC adapter cord is fully inserted into the wall outlet or extension cord. Always carefully disconnect all plugs by pulling on the plug and not on the cord.

DANGER - TO REDUCE THE RISK OF FIRE OR ELECTRIC SHOCK, CAREFULLY FOLLOW THESE INSTRUCTIONS For connection to a supply not in the U.S.A., use an attachment plug adapter of the proper configuration for the power outlet, if needed. The GC Ultimate controllers may contain a rechargeable lithium ion battery. Leakage of ingredients contained within the battery, or the combustion products of the ingredients, can cause personal injury as well as damage to other components. If battery leakage occurs, avoid contact with skin. If contact occurs, immediately wash thoroughly with soap and water. If liquid leaking from a battery comes into contact with your eyes, immediately flush thoroughly with water and see a doctor. To avoid battery leakage: Do not expose battery to excessive physical shock, vibration, or liquids. Do not disassemble, attempt to repair, or deform the battery. Do not dispose of battery in a fire. Do not touch the terminals of the battery or cause a short between the terminals with a metal object.

The GC Ultimate controller can emit radio waves that can affect the operation of nearby electronics, including cardiac pacemakers.

Do not operate the GC Ultimate controller within 9 inches of a pacemaker.

If you have a pacemaker or other implanted medical device, do not use the GC Ultimate controller without first consulting your doctor or the manufacturer of your medical device.

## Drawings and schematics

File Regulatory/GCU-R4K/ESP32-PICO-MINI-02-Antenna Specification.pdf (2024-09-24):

## 6 Antenna Specifications

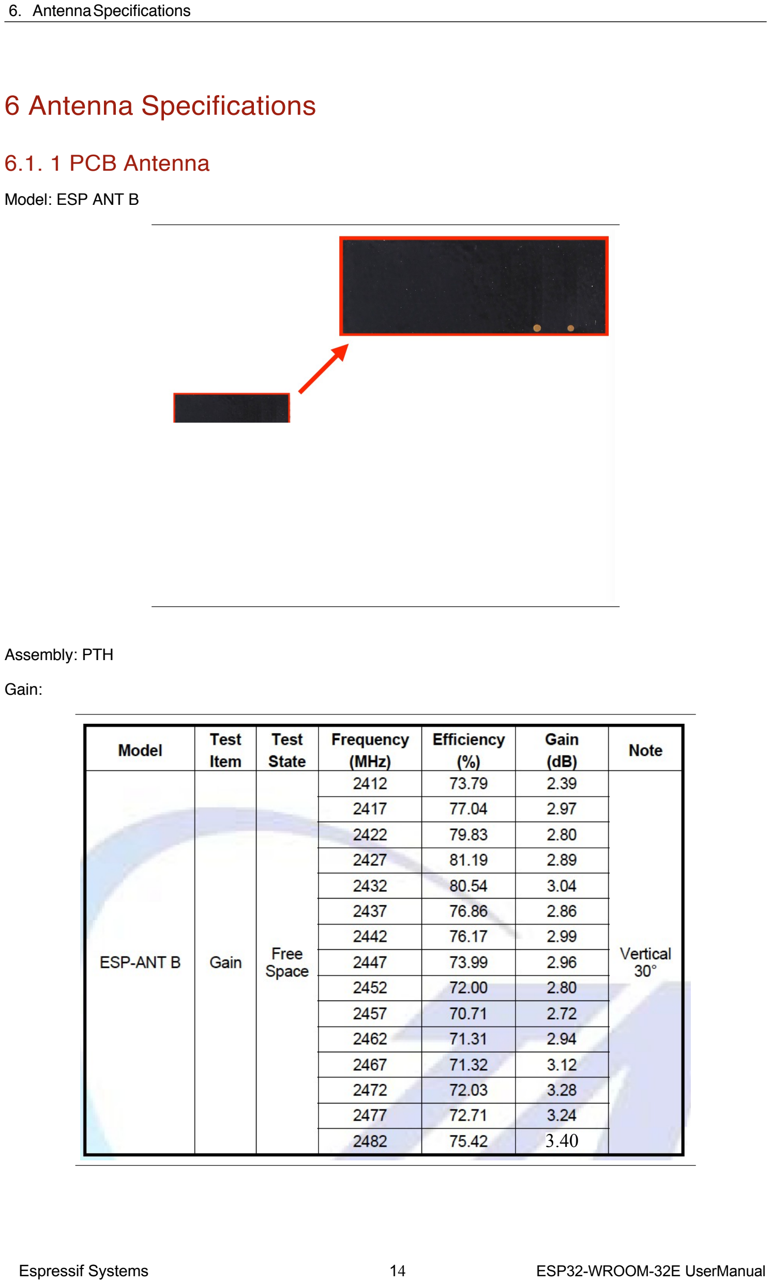
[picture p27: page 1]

6. AntennaSpecifications

### 6.1. 1 PCB Antenna

Model: ESP ANT B

Assembly: PTH

Gain:

Espressif Systems | 14 | ESP32-WROOM-32E UserManual

3.40

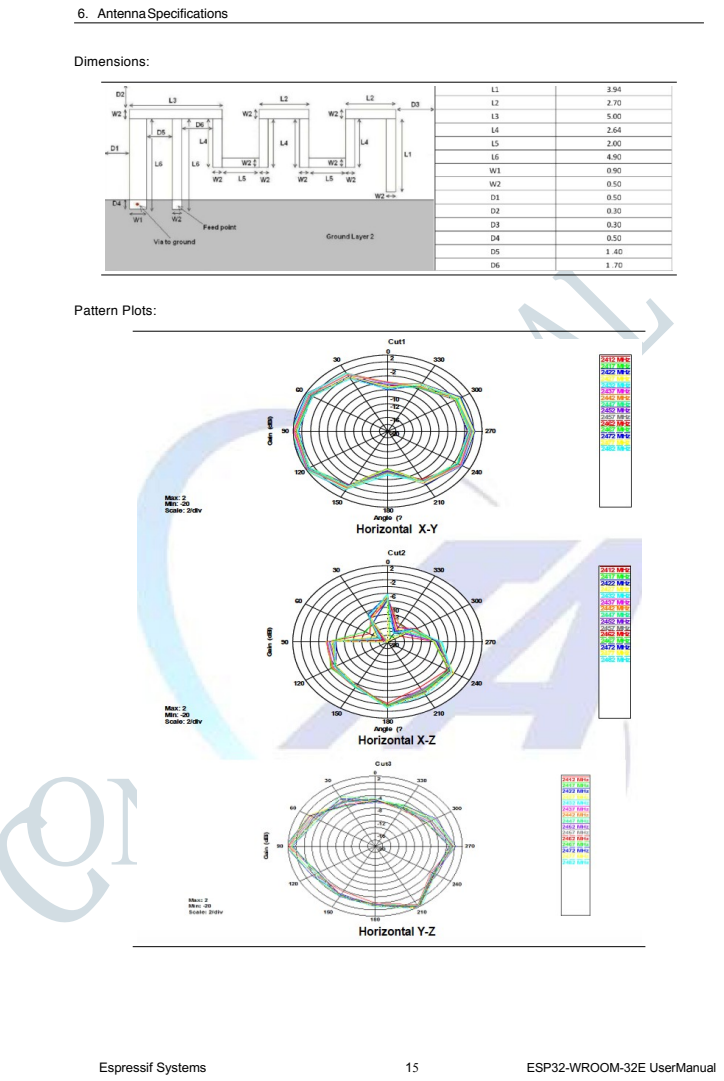
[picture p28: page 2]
ONFID; Dimensions:; Pattern Plots:; Espressif Systems; ESP32-WROOM-32E UserManual

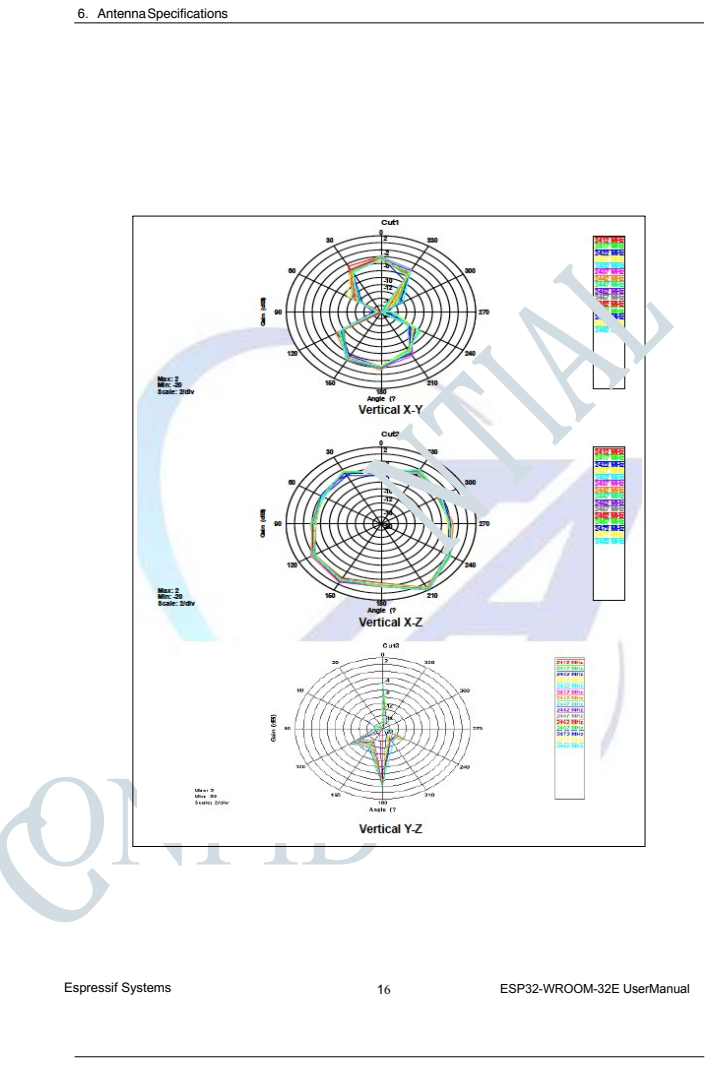
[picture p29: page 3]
ONFID; Espressif Systems; ESP32-WROOM-32E UserManual

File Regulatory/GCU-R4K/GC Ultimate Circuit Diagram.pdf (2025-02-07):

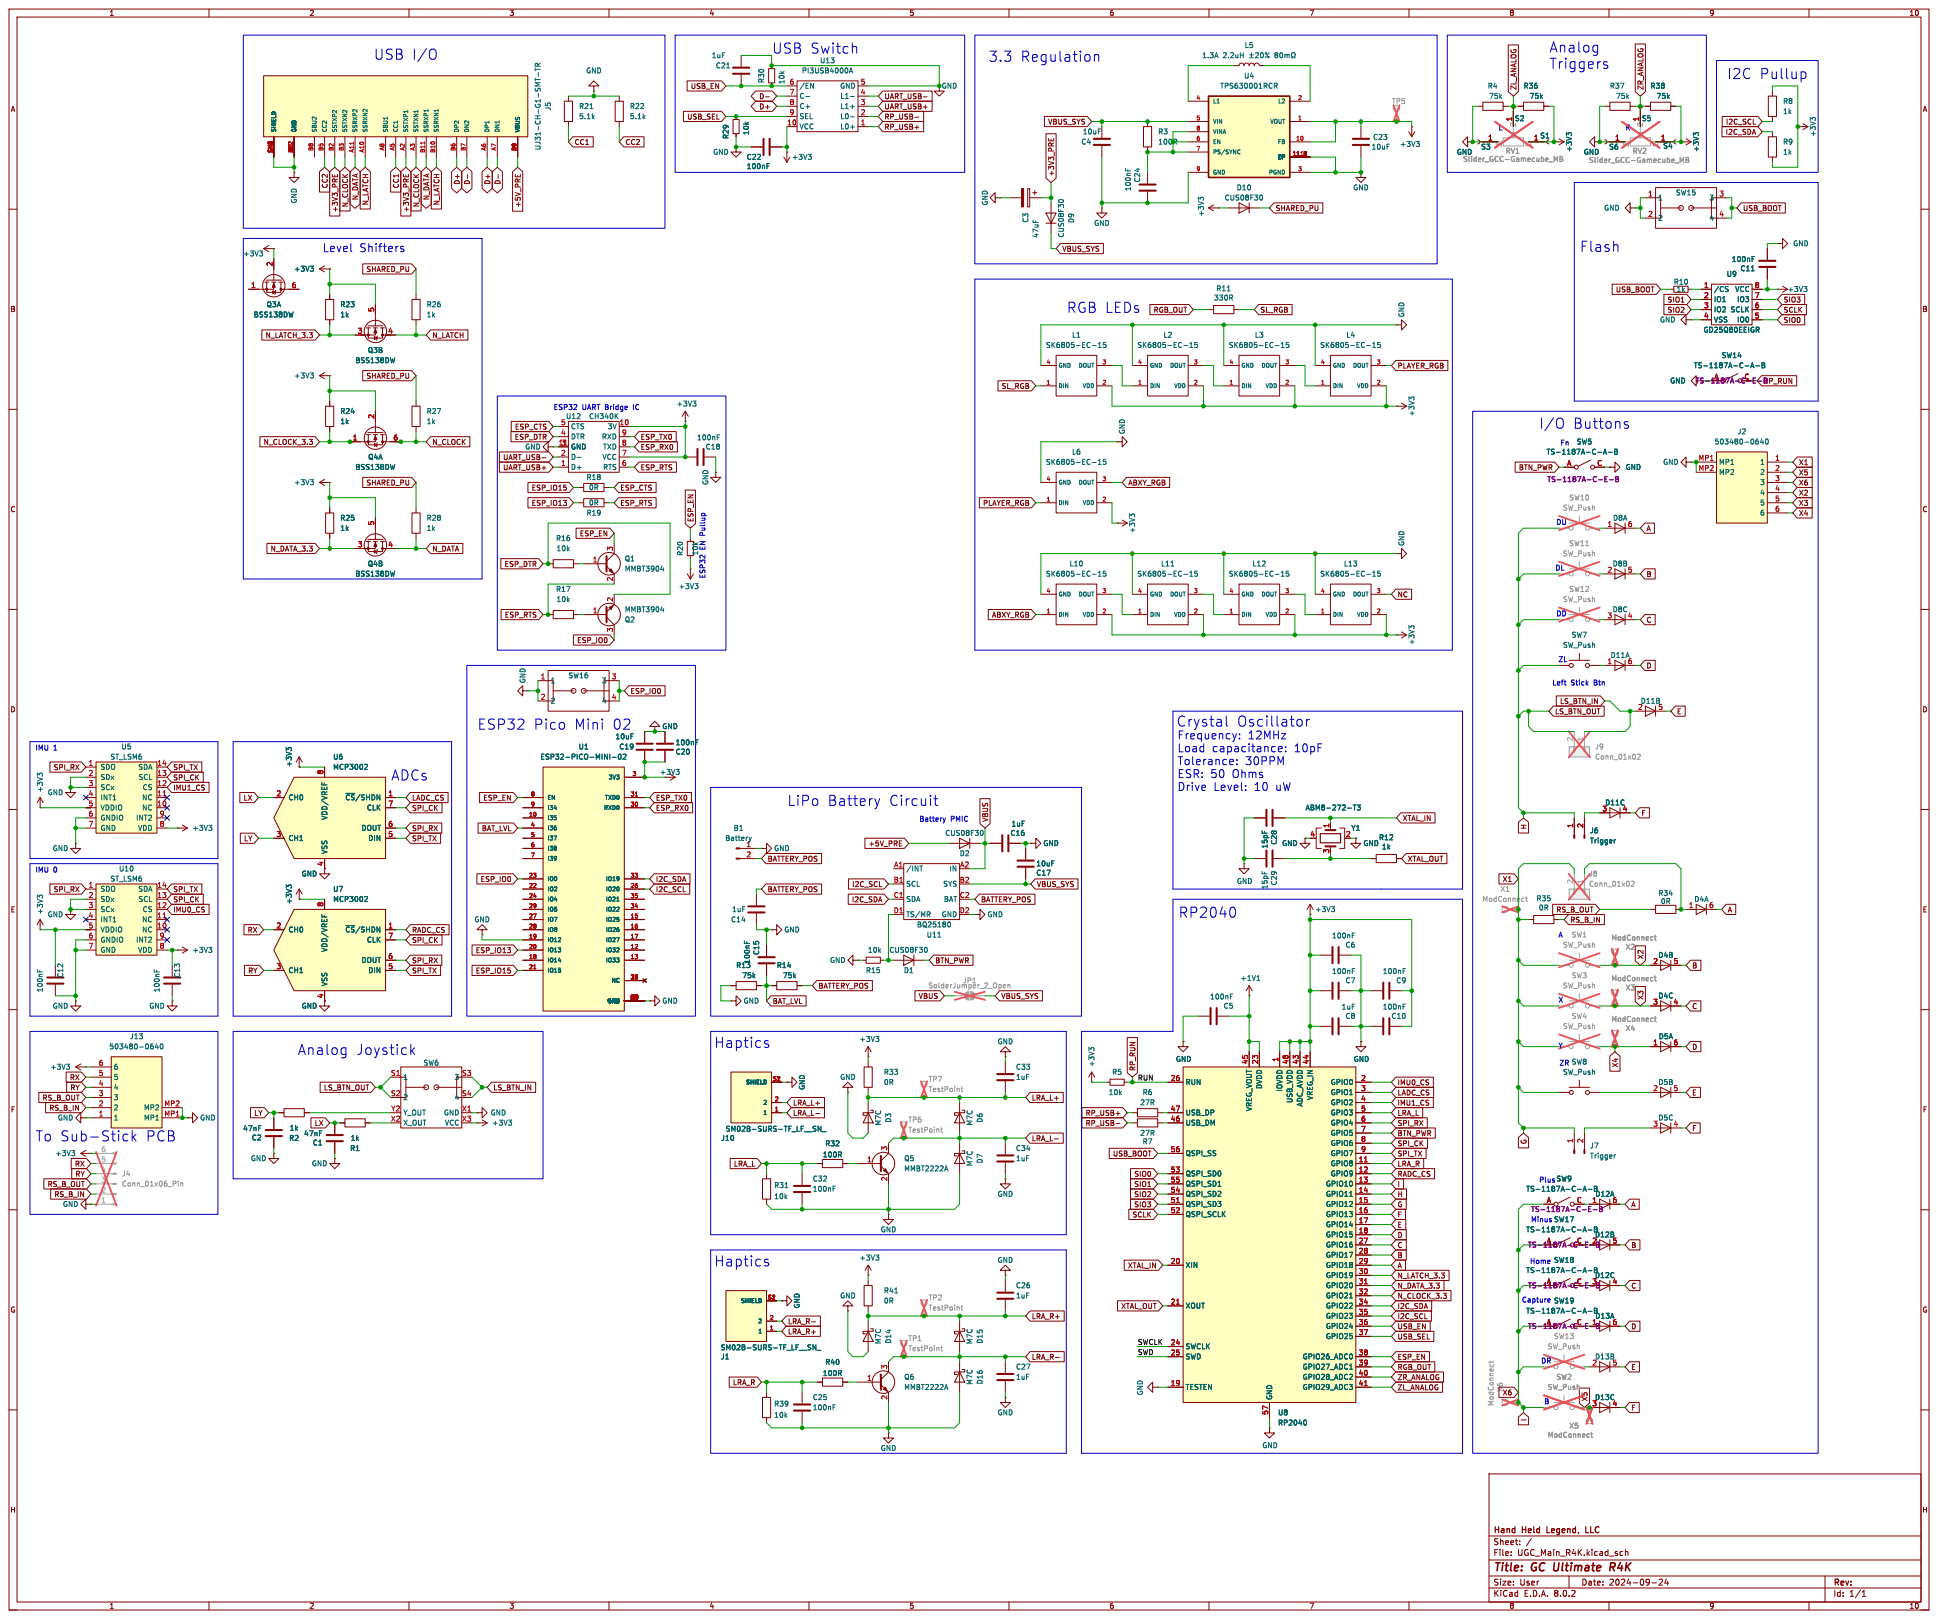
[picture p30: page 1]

1 GPIO8 11 GPIO9 12 GPIO10 13 GPIO11 14 GPIO12 15 GPIO13 16 GPIO14 17 GPIO15 18 TESTEN 19 GPIO0 2 XIN 20 XOUT 21 DVDD 23 SWCLK 24 SWD 25 RUN 26 GPIO16 27 GPIO17 28 GPIO18 29 GPIO1 3 GPIO19 30 GPIO20 31 GPIO21 32 GPIO22 34 GPIO23 35 GPIO24 36 GPIO25 37 GPIO26_ADC0 38 GPIO27_ADC1 39 GPIO2 4 GPIO28_ADC2 40 GPIO29_ADC3 41 ADC_AVDD 43 VREG_IN 44 VREG_VOUT 45 USB_DM 46 USB_DP 47 USB_VDD 48 GPIO3 5 QSPI_SD3 51 QSPI_SCLK 52 QSPI_SD0 53 QSPI_SD2 54 QSPI_SD1 55 QSPI_SS 56 GND 57 GPIO4 6 GPIO5 7 GPIO6 8 GPIO7 9 U8 RP2040 R29 10k

Left Stick Btn RGB LEDs

4 DIN 5 DOUT 6 CLK 7 VDD/VREF

1 GPIO8 11 GPIO9 12 GPIO10 13 GPIO11 14 GPIO12 15 GPIO13 16 GPIO14 17 GPIO15 18 TESTEN 19 GPIO0 2 XIN 20 XOUT 21 DVDD 23 SWCLK 24 SWD 25 RUN 26 GPIO16 27 GPIO17 28 GPIO18 29 GPIO1 3 GPIO19 30 GPIO20 31 GPIO21 32 GPIO22 34 GPIO23 35 GPIO24 36 GPIO25 37 GPIO26_ADC0 38 GPIO27_ADC1 39 GPIO2 4 GPIO28_ADC2 40 GPIO29_ADC3 41 ADC_AVDD 43 VREG_IN 44 VREG_VOUT 45 USB_DM 46 USB_DP 47 USB_VDD 48 GPIO3 5 QSPI_SD3 51 QSPI_SCLK 52 QSPI_SD0 53 QSPI_SD2 54 QSPI_SD1 55 QSPI_SS 56 GND 57 GPIO4 6 GPIO5 7 GPIO6 8 GPIO7 9 GND GND

Id: 1/1 Title: GC Ultimate R4K

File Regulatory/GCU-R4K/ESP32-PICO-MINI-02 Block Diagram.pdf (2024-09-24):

# 2 Block Diagram

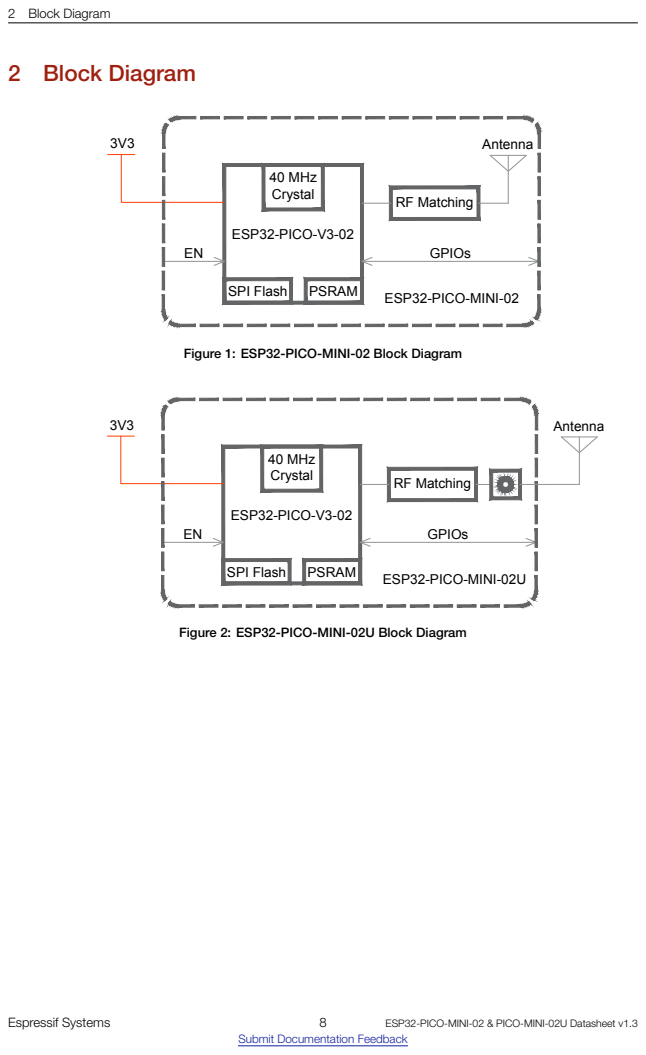
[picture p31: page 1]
2 Block Diagram; SPI Flash; ESP32-PICO-V3-02; RF Matching; 40 MHz Crystal; ESP32-PICO-MINI-02; GPIOs; PSRAM; Antenna; ESP32-PICO-MINI-02U; Espressif Systems

Figure 1: ESP32-PICO-MINI-02 Block Diagram

Figure 2: ESP32-PICO-MINI-02U Block Diagram

ESP32-PICO-MINI-02 & PICO-MINI-02U Datasheet v1.3

Submit Documentation Feedback

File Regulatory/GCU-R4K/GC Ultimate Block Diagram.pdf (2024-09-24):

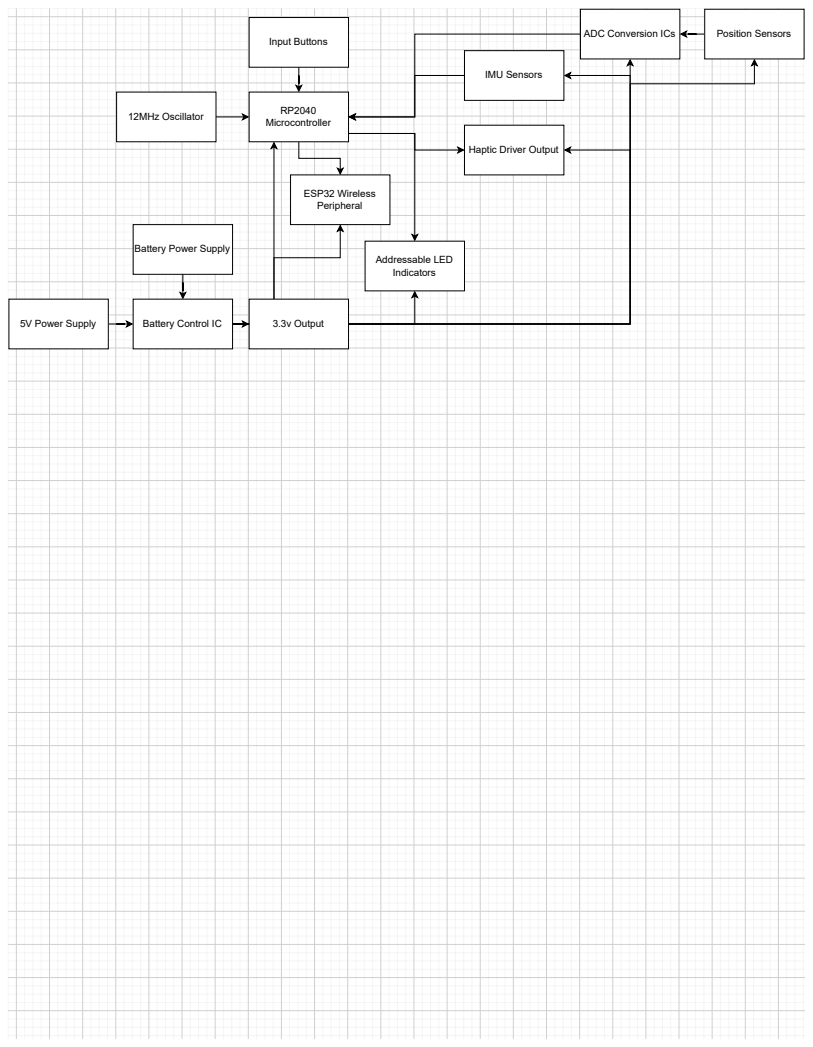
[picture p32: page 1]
12MHz Oscillator; Microcontroller; 5V Power Supply; 3.3v Output; Position Sensors; Input Buttons; IMU Sensors

ADC Conversion ICs

Haptic Driver Output

ESP32 Wireless
Peripheral

Battery Power Supply

Addressable LED
Indicators

Battery Control IC

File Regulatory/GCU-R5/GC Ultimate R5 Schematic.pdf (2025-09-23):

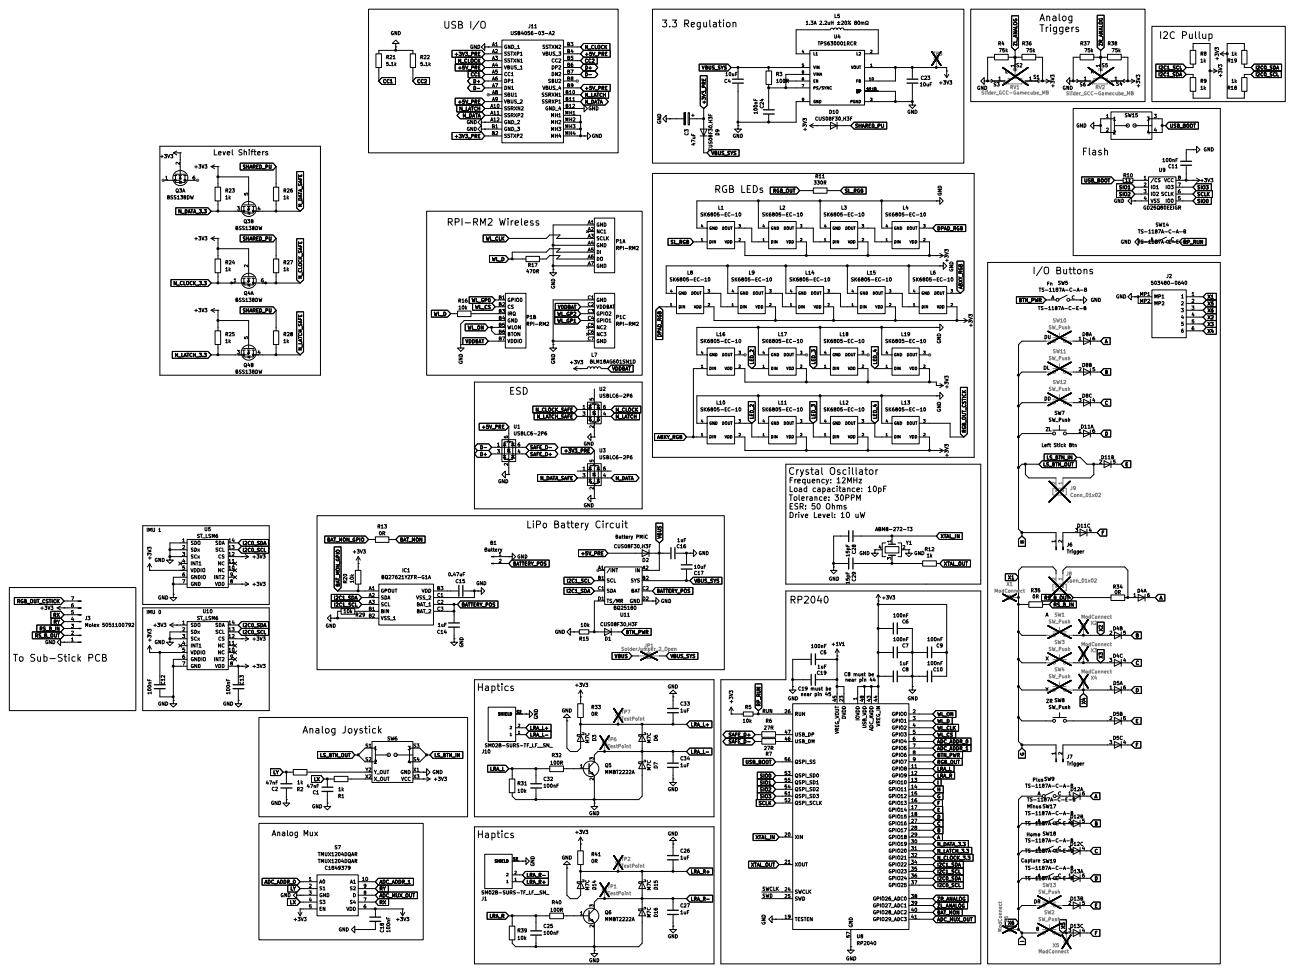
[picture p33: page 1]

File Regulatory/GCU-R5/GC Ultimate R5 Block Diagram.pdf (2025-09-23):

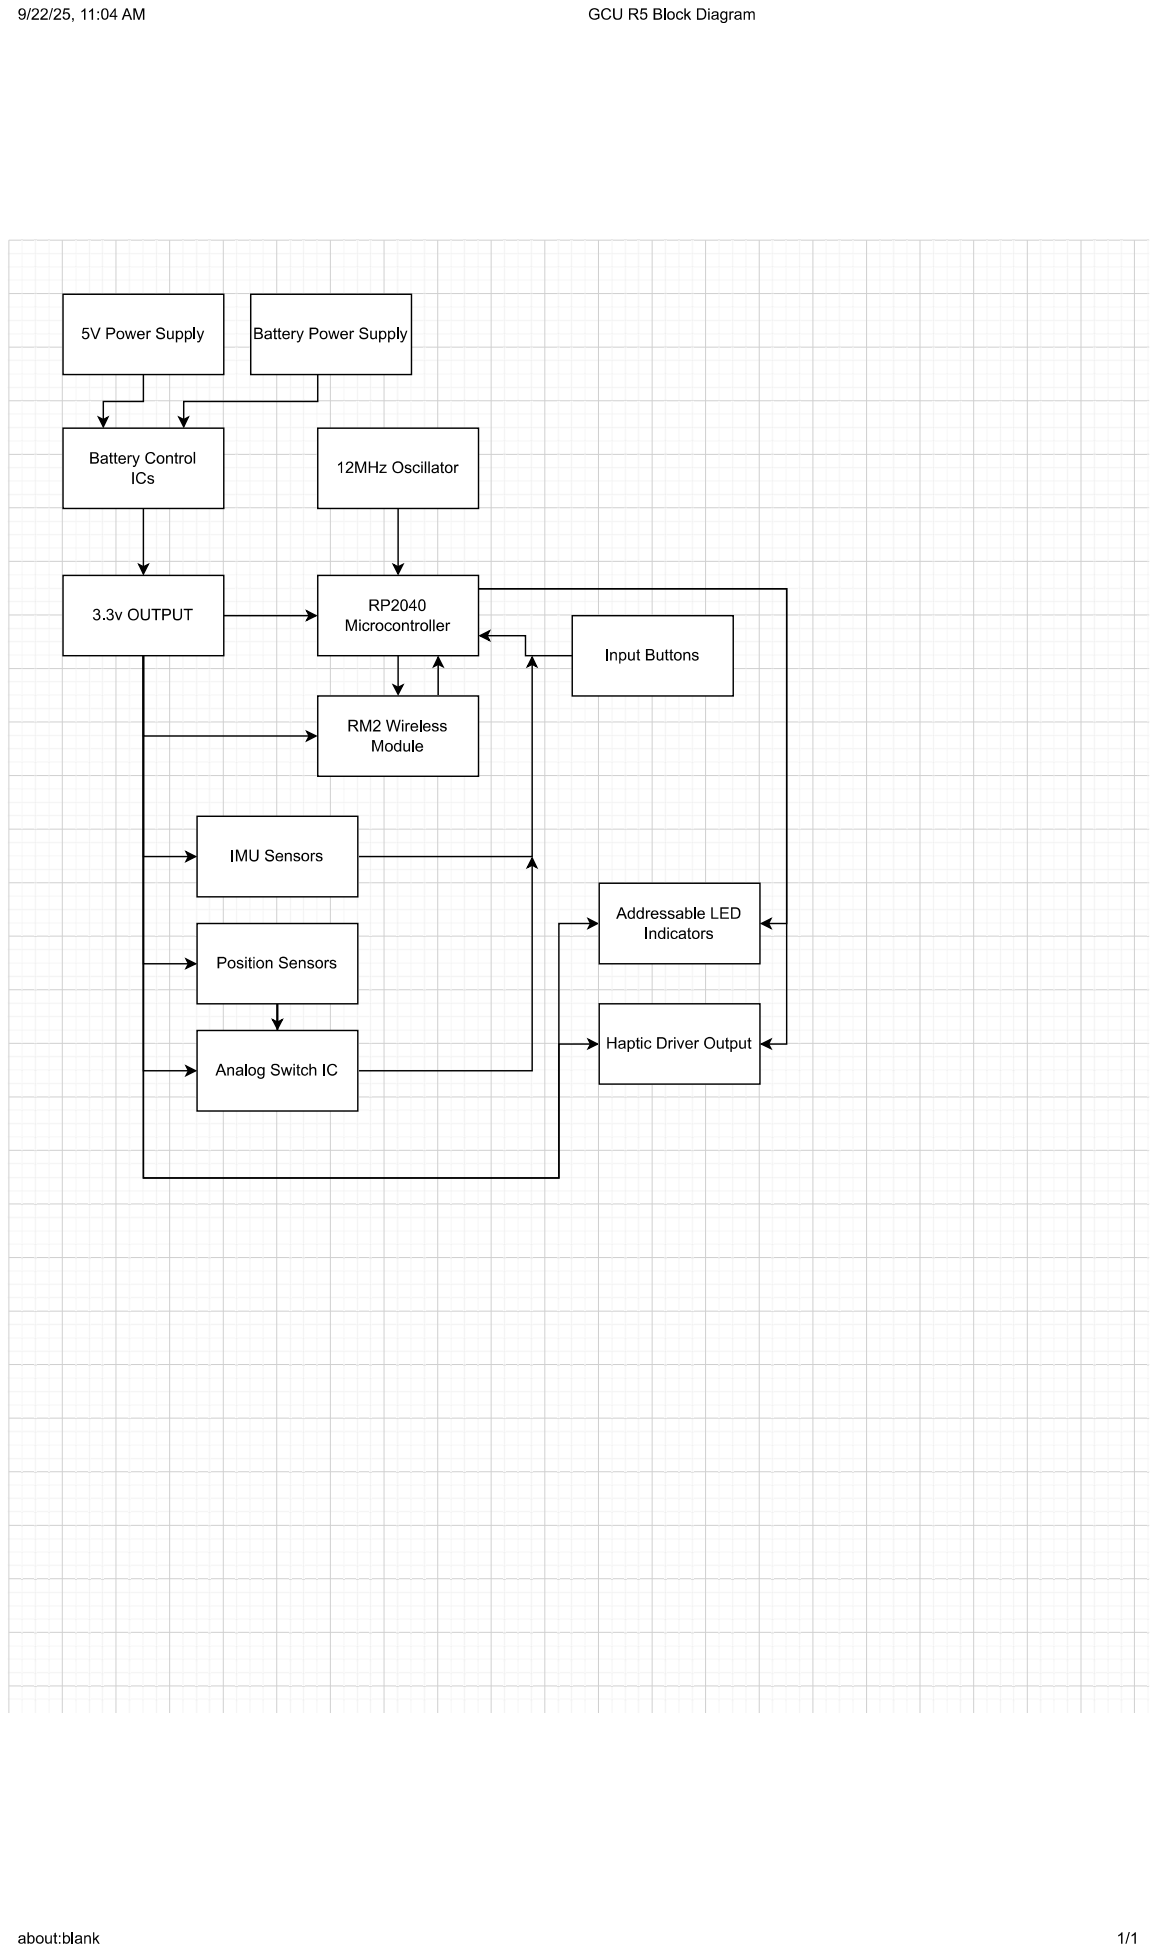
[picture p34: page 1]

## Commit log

2023-12-14 Checkpoint 2
    [UGC_Main.kicad_pcb, UGC_Main.kicad_sch, UGC_USBC.kicad_pcb]
2023-12-14 Updates
    - Stick PCB
    - USB C pcb
    - trigger PCB
    [UGC_Main.kicad_sch, UGC_SubStick.kicad_pcb, UGC_SubStick.kicad_sch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]
2023-12-14 Production files
    [UGC_Main-B_Cu.gbr, UGC_Main-B_Mask.gbr, UGC_Main-B_Paste.gbr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]
2023-12-15 Update
    - Add initial firmware
    - Fix PCB trace for SPI RX pin
    [GC-Ultimate Hardware Kits.xlsx, GC-Ultimate PCB Notes.xlsx, GatePlate Octagon.step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]
2023-12-16 Power update
    - Update regulator
    - Add relevant components
    [GC-Ultimate PCB Notes.xlsx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]
2023-12-20 Update
    - Remove 3d files
    - Update power regulator and schematic
    [GatePlate Octagon.step, GatePlate Round.step, MembraneTriggerHolder.step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]
2024-01-22 Firmware test
    [GC-Ultimate PCB Notes.xlsx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]
2024-02-06 Unify USB C connector
    Unified USB-C Connection
    Reliability issues present with type C pogo pin board
    [GC-Ultimate PCB Notes.xlsx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]
2024-03-06 PCB Update
    - Add RESET switch
    - Add ESP bootloader switch
    - Adjust screw holes for trigger bracket mount
    [UGC_Main.kicad_pcb, UGC_Main.kicad_sch]
2024-03-07 Update production files
    [GC-Ultimate PCB Notes.xlsx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]
2024-03-26 Update board
    [UGC_Main-B_Cu.gbr, UGC_Main-B_Mask.gbr, UGC_Main-B_Paste.gbr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]
2024-04-27 4.262024 Burn Test Update.
    [UGC_Main-B_Cu.gbr, UGC_Main-B_Mask.gbr, UGC_Main-B_Paste.gbr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]
2024-05-17 5.17.2024 Updates
    - Fix PCB with fuse removal (3.3 undervolted)
    - Fixes for N64 mode
    - Fixes for GameCube mode + new input mode support for more titles
    [UGC_Main.kicad_pcb, UGC_Main.kicad_sch]
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2024-06-18 New stuff
    [UGC_Main.csv, UGC_Main.kicad_pcb, UGC_Main.kicad_sch]
2024-06-18 Update revision
    [UGC_Main.kicad_pcb, UGC_Main.kicad_sch]
2024-06-20 Add cad files
    [1.5mm_MechTriggerPCB.dxf, CaptureButton.step, CaptureButton.stl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]
2024-06-20 Mech trigger stuff
    [UGC_MechTrigger-B_Cu.gbr, UGC_MechTrigger-B_Mask.gbr, UGC_MechTrigger-B_Paste.gbr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]
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2024-06-26 Updates across the board
    [GC Trigger Kailh Stem.step, GC Trigger Kailh Stem.stl, NuMechTriggerBracket.step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]
2024-07-04 Main board update
    Use new TMR stick on main board
    [NuMechTriggerBracket.step, NuMechTriggerBracket.stl, UGC_Main.kicad_pcb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]
2024-07-06 R4 updates to hardware
    [1.5mm_MechTriggerPCB.dxf, CaptureButton.step, GC Trigger Kailh Stem.step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]
2024-07-14 Update PCB r4
    [GCUltimate_R4 Notes.xlsx, Main_R4_BOM.csv, NuMechTriggerBracket.step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]
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2024-07-15 FW Update
    - Fix GC Mode vibrate
    - Analog trigger disable function
    - Better analog trigger calibration function
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2024-08-03 Rumble changes and more
    [UGC_Main-B_Cu.gbr, UGC_Main-B_Mask.gbr, UGC_Main-B_Paste.gbr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]
2024-08-03 Fix battery check
2024-08-05 CRC i2c bug resolution
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2024-08-24 Add press fit insert
    [UGC_Main_R4.csv, UGC_Main_R4.kicad_sch]
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2024-08-26 Fix bad geometry on trigger bracket
    [MechTriggerBracket.iges, MechTriggerBracket.step]
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2024-08-31 Update PCB files R4K
    [UGC_Main_R4-B_Cu.gbr, UGC_Main_R4-B_Mask.gbr, UGC_Main_R4-B_Paste.gbr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]
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2024-09-04 Updates to CAD
    - Remove legacy STLs
    - Add new STLs (incomplete)
    - Update Top/Lower shell for C stick tolerances
    - Add new analog stick CAD models and STL
    [CaptureButton.stl, GC Trigger Kailh Stem.stl, GatePlateOctagon.stl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]
2024-09-12 Update CAD
    - Fix joystick models to be more accurate
    -- Adjusted joystick distance to the PCB and double/triple checked all measurements/distances.
    -- Ensured the skirt length is appropriate now. The old model would slightly rub on some shells.
    - Update C stick distance for the C Stick PCB
    - Update shell files
    [MainStickFull.stl, Main_Body.iges, Main_Body.step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]
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2024-09-12 Update substick
    - Shorten height to better match OEM
    - Increase rubber thickness on C stick to ~1mm on the top portion nominal
    [SubStickFull.stl, Sub_Body.iges, Sub_Body.step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]
2024-09-19 Update CAD
    - Balds profile update for A and B buttons
    - Update Top/Bottom shells
    - Bottom shell as a small emblem courtesy of Potsy
    [A Button Bald.iges, A Button Bald.step, B Button Bald.iges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]
2024-09-19 Update shell files
    - Change fillet around A button
    - Change fillets around gateplate
    [GatePlateOctagon.iges, GatePlateOctagon.step, GatePlateOctagon.stl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]
2024-09-23 CAD Updates
    - Add small direction indicator bumps for peripheral buttons
    - Add VERSION txt
    - Remove IGES packages
    [A Button Bald.iges, B Button Bald.iges, CaptureButton.iges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]
2024-09-24 HW Test branch init
    [UGC_Main_R4K.kicad_pcb, UGC_SubStick_R4K.kicad_pcb]
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2024-09-24 Update PCB schematic
    fix diode issue
    [UGC_Main_R4K.kicad_sch]
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2024-09-27 CAD Mold Master Files
    [A_SKEL.stl, B_SKEL.stl, MOLD_WALL.stl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]
2024-09-28 Update CAD Mold models
    [MOLD_WALL.stl]
2024-09-29 Update menu button indicators
    [CaptureButton.iges, CaptureButton.step, HomeButton.iges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]
2024-10-23 Update CAD files
    - PCB uses a new socket type for the slider potentiometers
    [UGC_Main_R4K-B_Cu.gbr, UGC_Main_R4K-B_Mask.gbr, UGC_Main_R4K-B_Paste.gbr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]
2024-10-24 Update PCBs
    - New S1 variant
    - Update crystal and socket mounts for trigger sliders
    [UGC_Main_R4K.kicad_pcb, UGC_Main_R4K.kicad_sch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]
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2024-10-25 Update PCBs
    - Fix BOMs so they reference real part numbers
    [UGC_Main_R4K-B_Cu.gbr, UGC_Main_R4K-B_Mask.gbr, UGC_Main_R4K-B_Paste.gbr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]
2024-10-25 Fix some wrong MPNs
    [UGC_Main_R4K.csv, UGC_Main_R4K.kicad_sch, UGC_Main_S1.csv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]
2024-10-26 Minor updates to text
    [UGC_Main_R4K.kicad_pcb, UGC_Main_R4K.kicad_sch, UGC_Main_S1.kicad_sch]
2024-10-28 Resolve conflicts
    [UGC_Main_R4K.csv, socket_test.kicad_pcb, socket_test.kicad_sch]
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2024-10-29 Update PCB directory
    Accessory boards have been migrated to Open-GC-Ultimate
    [UGC_Main_S1-B_Cu.gbr, UGC_Main_S1-B_Mask.gbr, UGC_Main_S1-B_Paste.gbr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]
2024-10-30 PCB Production files update
    [GC Ultimate R4K.xlsx, GC Ultimate S1.xlsx, UGC_Main_R4K.csv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]
2024-11-08 Update main BOM excel
    [GC Ultimate R4K.xlsx]
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2025-01-13 Update BOM for diode
    [BOM GC Ultimate R4K.xlsx, GC Ultimate R4K.xlsx, UGC_Main_R4K.csv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]
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2025-01-17 Fix S1 diode BOM
    [UGC_Main_S1.csv]
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2025-07-15 Clean up shell files and some adjustments
    - New printables
    - new STEP and x_t solid files
    - Adjusted shell edges with fillet
    - Adjust material thickness under C stick area
    [A Button Bald.iges, A Button Bald.step, A_SKEL.stl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]
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2025-07-21 Update main PCB
    - Change RGB to 1.0mm variants
    - Change button footprints
    - Double up on ABXY rgb for better illumination
    [UGC_Main_R5-B_Cu.gbr, UGC_Main_R5-B_Mask.gbr, UGC_Main_R5-B_Paste.gbr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]
2025-07-21 S1 Version PCB Updates
    [UGC_Main_S1-B_Cu.gbr, UGC_Main_S1-B_Mask.gbr, UGC_Main_S1-B_Paste.gbr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]
2025-09-02 GCU R5 Update
    - Add fuel gauge IC
    [UGC_Main_R4K.kicad_pcb, UGC_Main_R4K.kicad_sch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]
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2025-09-23 GCUR5 Updates
    - Diode removed for 5V USB Input
    [UGC_Main_R5-B_Cu.gbr, UGC_Main_R5-B_Mask.gbr, UGC_Main_R5-B_Paste.gbr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]
2025-09-30 PCB Updates
    - Change potentiometer orientation for trigger sliders
    [UGC_Main_R5-B_Cu.gbr, UGC_Main_R5-B_Mask.gbr, UGC_Main_R5-B_Paste.gbr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]
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
